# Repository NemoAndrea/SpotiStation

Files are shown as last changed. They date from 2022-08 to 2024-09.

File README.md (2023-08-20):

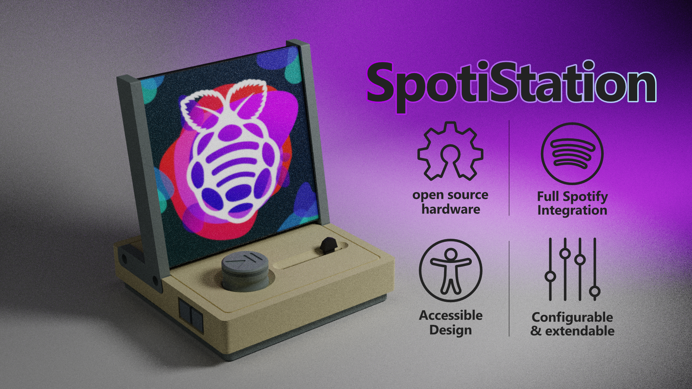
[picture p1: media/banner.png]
banner image


# SpotiStation - an accessible music player
A **Raspberry Pi** powered **Spotify** music player that aims to be **easy to use for people with cognitive or physical disabilities (e.g. Alzheimer's or MS)**, and allow them to enjoy music independently. 

To suit this purpose, the music player has an **extremely simple interface & operation**. A big play/pause button, a physical linear volume slider, and two side buttons that handle convenience functions, but can be omitted.

While accessibility is the primary aim of the design, this does not mean it cannot be used by a broader audience. If you like the idea of seeing the album art of your Spotify songs, and the physicality of hardware buttons, it would not look out of place in a living room. 

Features

* RGB led matrix that displays cover art and serves as basic visual interface
* Night mode that turns off the display and stops playback at user-set interval
* Lock mode, for caretakers to stop playback for a day
* Audio playback via Bluetooth simplifies wiring and mounting
* Only one plug (power supply)
* Configurable playlist selection, only use a subset of your Spotify playlist for playback
* Playback controllable via Spotify API (e.g. via phone or computer)
* Total parts cost €163 (**excluding printed parts**).
* 3D printed enclosure, making modification easy
* Open python code, low barrier to modification

> **Note** SpotiStation does **not** have any built-in speakers, it needs external bluetooth speakers.

> **Note** SpotiStation is a **standalone** Spotify player and does **not** require a computer or mobile device to run or handle any aspect of playback, although these devices integrate well with the device thanks to the Spotify multi-device API.

### 📖 Manual

A usage manual explaining features and going into details about how features are implemented can be found [on the project wiki](https://github.com/NemoAndrea/SpotiStation/wiki).

### 🔨 Assembly

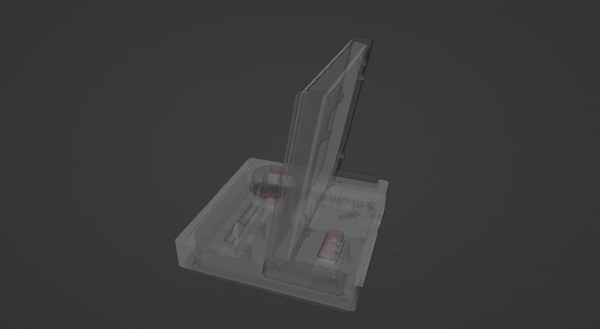
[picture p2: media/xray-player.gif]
xray view of spotistation


The assembly of the music player will require some dexterity, screwdrivers, and soldering setup and know-how. If you don't have a soldering setup, you could ask a friend or look for a [maker space](https://en.wikipedia.org/wiki/Hackerspace) that will have the right gear.

A [step-by-step walkthrough of assembly](docs/assembly.md) is available. 

> Feedback on what parts of the assembly are not explained well or are particularly complicated is greatly appreciated. Overly complicated steps could be fixed in future design revisions.

If you find yourself in a situation where accessing the SpotiStation is often difficult and moving the player is not an option, you could consider sourcing the parts for and printing a wireless remote 🎮 for the system. Total parts cost (excluding printed parts) is only around 10 euros, so it is cheap to add. Check out the separate instructions for [the simple wireless remote](docs/assembly-optional-remote.md).

### 💻 Software Setup

The software setup is streamlined as much as possible, but there are some unavoidable difficult steps due to the need to fetch API keys and such for Spotify. If you know how to SSH into your Raspberry Pi, you should be good to go.

The [full step-by-step walkthrough](docs/setup.md) should let you get your own player up and running in no time! 

### 🤔 Alternative solutions

There are other simple music player that focus on accessibility for people with physical or cognitive disabilities. I suggest you check them out and see if they may be better suited for your needs. They are not open source or easily modifiable, but require minimal setup. 

* [the bbrain player](https://bbrain.eu/bbrain-muziekspeler/) - super simple operation, radio and MP3, nice administrator features (hide buttons)
* [The lift Player by smpl](https://smpltec.com/liftplayer-buy-now-us) - super simple operation, plays MP3 files, some administrator features (lock volume)
* [the relish radio player](https://relish-life.com/us/music/radios/relish-radio) - primarily a radio, but can playback MP3 from USB stick
* [the simple music player by iGuerburn](https://www.iguerburn.com/products/dementia-music-player) - plays MP3 files

And because open projects are cool, I will list some other open source projects below

* [dqmusicbox by Ross Porter](https://dqmusicbox.com/) - simple operation, plays MP3 files

### 🙏 Acknowledgements

The programmatically generated text in the UI uses the [silkscreen font by Jason Kottke](https://kottke.org/plus/type/silkscreen/). It is converted to a PIL font for display purposes.

This project is building on similar projects that use the RGB matrix to show album Art. A non-exhaustive list:

* The [spotipi project](https://github.com/ryanwa18/spotipi)  by Ryan Ward
* The [thirtytwopixels project](https://github.com/fspoettel/thirtytwopixels) by Felix Spöttel 

This project was significantly improved by insights gained during the [Delft Open Hardware Academy](https://www.openhardware.academy/01_Welcome.html).

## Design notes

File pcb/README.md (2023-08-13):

## SpotiStation shim PCB

This a simple PCB that minimises the spaghetti inside the SpotiStation enclosure. It should be fairly cheap to have it manufactured (less than 6 euros at [Aisler](https://aisler.net/)) with the most basic options.



### Edge.cuts

Board outline is specified in `edge-cuts.dxf` which is generated from the FreeCAD file `edge-cuts.FCStd` file using the 'new' dxf export.

To import it (or modified versions) to kicad, do the following:

1. Open PCB editor
2. File > Import > Graphics
3. Select the `edge-cuts.dxf` file 
4. Placement: at X=`150.82` Y=`106.32`. Make sure to import to the edge.cuts layer and keep the scale to 1. Line width can be chosen at random; 0.1mm is fine.

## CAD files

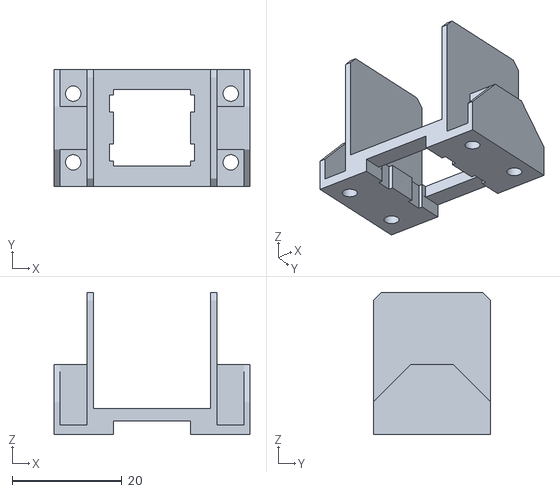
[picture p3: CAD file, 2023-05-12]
3D-printing/stl/MainButton-mount.stl
35.8 x 21.4 x 26.0

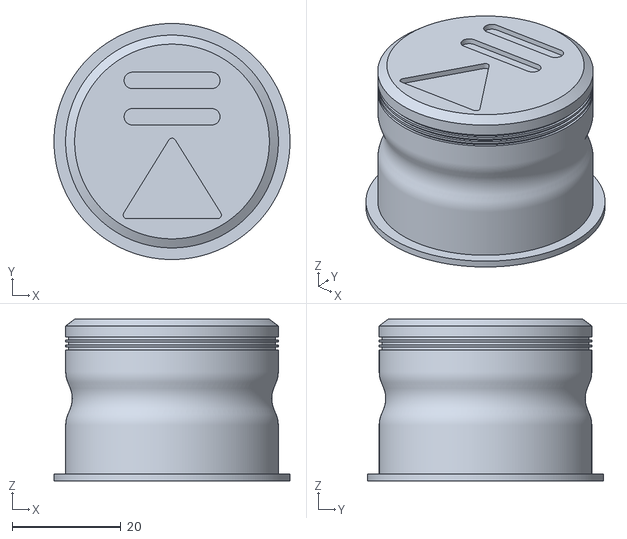
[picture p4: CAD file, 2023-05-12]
3D-printing/stl/MainButton.stl
43.3 x 43.3 x 29.7

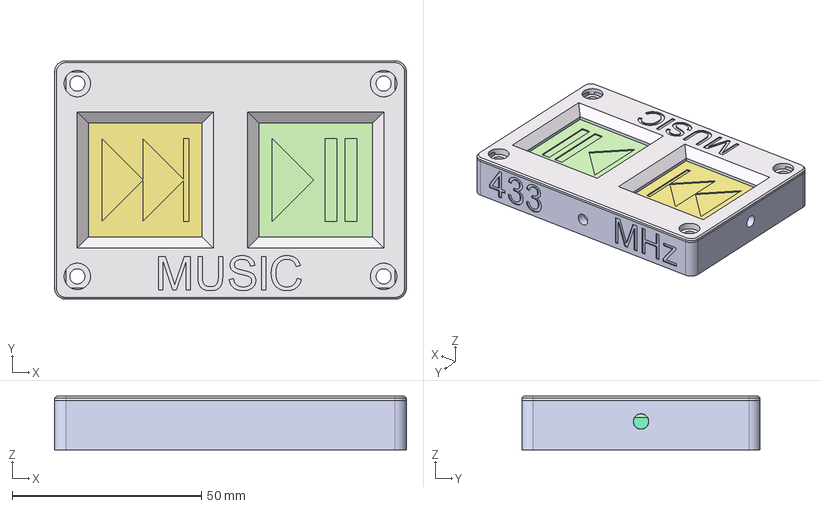
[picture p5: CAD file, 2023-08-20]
3D-printing/source/remote.FCStd
93.0 x 63.0 x 14.2 mm
remote-pcb
bulk
actuator-left
actuator-right
front-plate

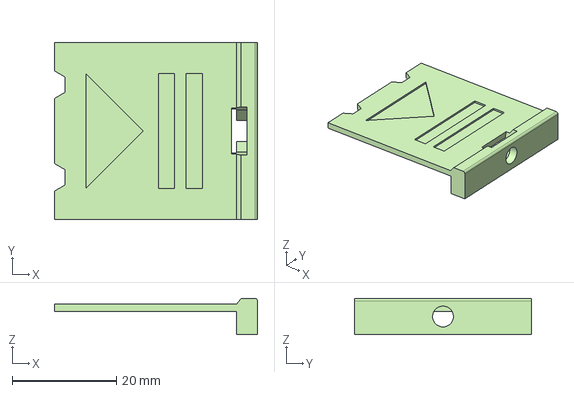
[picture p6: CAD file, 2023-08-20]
3D-printing/step/433_remote_button_RIGHT.step
39.0 x 34.0 x 7.00 mm

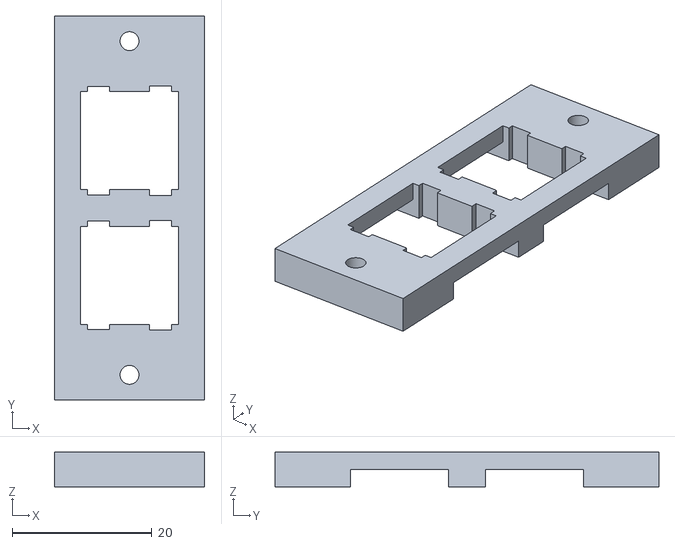
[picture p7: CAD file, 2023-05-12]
3D-printing/stl/Baseplate-button-bracket.stl
21.5 x 55.0 x 5.00

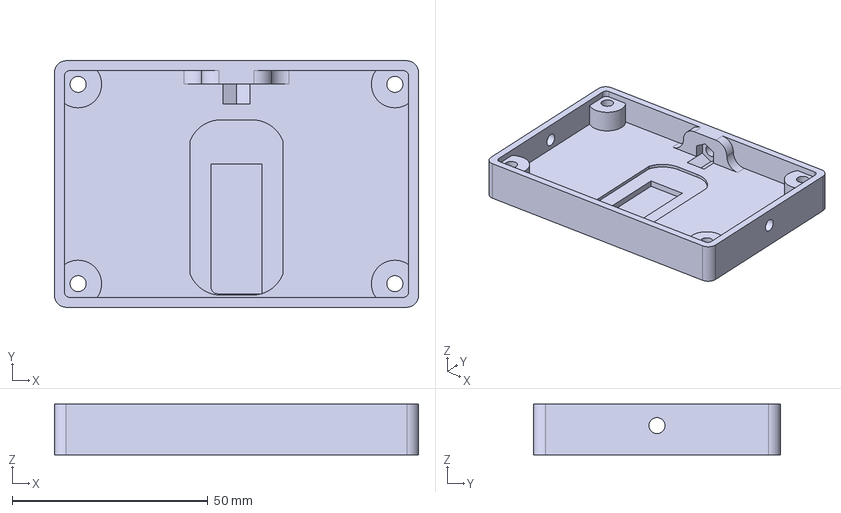
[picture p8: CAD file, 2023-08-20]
3D-printing/step/433_remote_base.step
93.0 x 63.0 x 13.0 mm

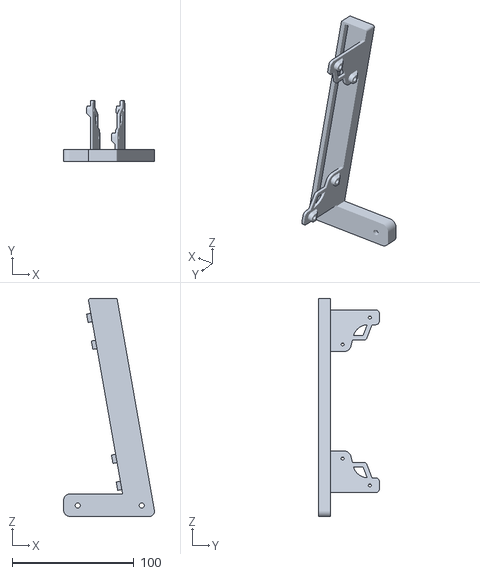
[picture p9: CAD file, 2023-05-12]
3D-printing/stl/Display-Arm-Left.stl
74.6 x 49.9 x 178.8

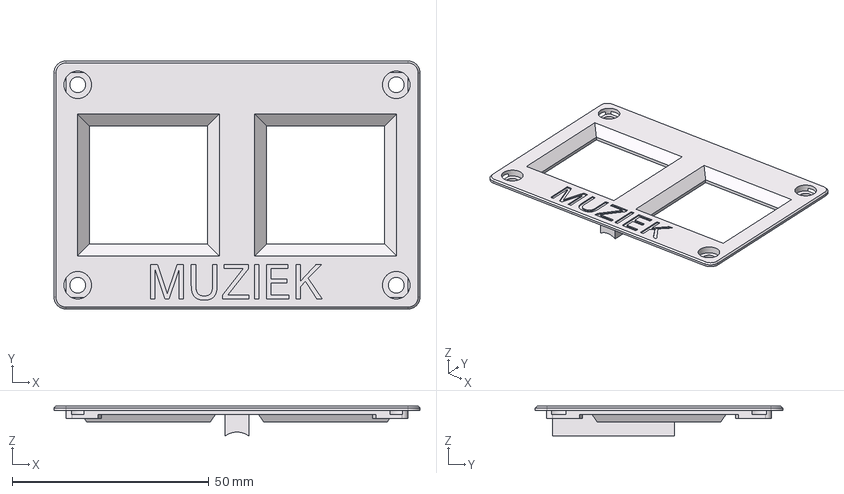
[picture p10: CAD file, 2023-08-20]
3D-printing/step/433_remote_lid.step
93.0 x 63.0 x 7.61 mm

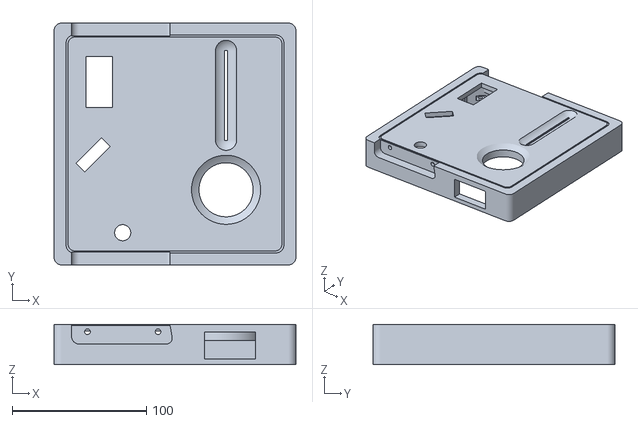
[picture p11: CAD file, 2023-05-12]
3D-printing/stl/Case.stl
180.0 x 180.0 x 30.0

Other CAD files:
pcb/edge-cuts.FCStd
3D-printing/step/433_remote_button_LEFT.step
3D-printing/stl/Display-Arm-Right.stl
pcb/edge-cuts.dxf

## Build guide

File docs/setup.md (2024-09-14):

# Software Setup 

> [!CAUTION]
> The instructions in the section below can be a bit technical and should be streamlined. If you are planning on following them and get stuck, feel free to send an email and I will try to help out.

We are assuming the code is run from a raspberry pi running `Raspberry Pi OS Lite 32-Bit` and that the raspberry pi has some way to connect to Wi-Fi. Bluetooth connectivity is required if speakers are to be driven wirelessly (as opposed to via 3.5mm jack of the Pi).

> [!IMPORTANT]
> We are assuming you will configure your installation of Raspberry Pi OS with username `musicpi` and device name `SpotiStation`. 

Raspbian OS Lite comes with A Python 3 installation, and a GPIO library, so that will be pre-installed. But we will still need to get `pip` installed. 

```
sudo apt-get install python3-pip -y
```

To drive the **Adafruit NeoSlider** we will need to get the appropriate package

```
pip3 install adafruit-circuitpython-seesaw
```

In addition, we will need to activate the `I2C` (hardware) interface on the Pi (disabled by default). We can do this in the configuration of the raspberry pi. 

```
sudo raspi-config
```

In the configuration menu, go to `Interface Options`, enable `I2C` and close out of the menu. 

For reasons that are not entirely clear to me, the NeoSlider does not work well with the default i2c bus frequency. It will randomly lock up the bus, or read values beyond it's normal valid range (0,1023). To fix this, we need to [change the i2c bus frequency to 400kHz](https://gist.github.com/ribasco/c22ab6b791e681800df47dd0a46c7c3a) on the Pi. 

1. Open system config `sudo nano /boot/config.txt`. Be careful not to mess anything up there.
2. Find the line `dtparam=i2c_arm=on` 
3. Add `i2c_arm_baudrate=400000` to the **same** line (comma separated), so it now reads `dtparam=i2c_arm=on,i2c_arm_baudrate=400000`
4. Save and exit `nano` (ctrl s, ctrl x)
5. Reboot (maybe even power cycle)

We will also need to be able to control the system volume, for which we will need another python package

```
pip3 install pyalsaaudio
```

### 💾 Download the SpotiStation code

We will need to get the SpotiStation code onto the raspberry Pi. You can either

1. Clone this repository directly (this will get you the latest version of the code)
2. Download the latest release (generally older but more stable in principle)

Whichever option you chose, we want the contents to be stored in a folder called `SpotiStation` located **in the home directory**. Make one and enter it by

 ```
cd 
mkdir SpotiStation
 ```

And then for option (1) we use

```
git clone https://github.com/NemoAndrea/SpotiStation.git SpotiStation
```

And for option (2) 

```
curl -L https://api.github.com/repos/NemoAndrea/SpotiStation/tarball/<version> -o spotistation.tgz
tar -xvf spotistation.tgz --strip-components=1 -C SpotiStation
```

Where you replace `<version>` with whichever release is the latest, e.g. `v0.1.0`

### 🌈 RGB panel setup

We follow [Adafruit's guide](https://learn.adafruit.com/adafruit-rgb-matrix-bonnet-for-raspberry-pi/driving-matrices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) and install the drivers by Henner Zeller h.zeller@acm.org. Download and run the installer script by:

```
curl https://raw.githubusercontent.com/adafruit/Raspberry-Pi-Installer-Scripts/main/rgb-matrix.sh >rgb-matrix.sh
sudo bash rgb-matrix.sh
```
And follow the instructions in the installer script. We are using the matrix bonnet, not the hat with RTC. We also want the `quality` option.

* Solder jumper between 4 and 18, picture quality is not good enough without. Analog audio (3.5mm jack or HDMI) will be disabled, but Bluetooth audio is fine.
* Enable the CPU core reservation (pi 3, zero 2, and 4) in `/boot/cmdline.txt`, by adding `isolcpus=3` to the file (space separated from other items in that file). Example contents: ```console=serial0,115200 console=tty1 root=PARTUUID=060e4657-02 rootfstype=ext4 fsck.repair=yes rootwait isolcpus=3``` 

### 🎵 Setup - Spotify (background)

To stream Spotify, we will use [spotifyd](https://github.com/Spotifyd). We need to install the latest release (for ARMv6), as per the instructions laid out on [their raspberry pi guide page](https://spotifyd.github.io/spotifyd/installation/Raspberry-Pi.html). For completeness I will cover the contents of their page here. If in doubt, follow the instructions on `spotifyd`'s page.  Make sure you get the latest release. At the time of writing, the latest version is `0.3.3`, so we install that with:

```
wget https://github.com/Spotifyd/spotifyd/releases/download/v0.3.3/spotifyd-linux-armv6-slim.tar.gz
```

> This setup assumes you are downloading this into your home directory on the raspberry pi. (type `cd` to go there if you are not sure)

The command above will give you a `tar.gz` archive, which you can unpack with

```
tar -xf <name of downloaded file>.tar.gz
```

Now we need to create a config file where we set up`spotifyd` to our liking.

```
mkdir ~/.config/spotifyd/
```

> It may be the case that you do not have a `.config` folder on your Pi. If so, just create an empty one by `mkdir ~/.config`

and again we must create and edit this file in `nano` (use `nano ~/.config/spotifyd/spotifyd.conf`) and paste the following information into it:

```toml
[global]
#username_cmd = "jq -r .username /home/musicpi/.cache/spotifyd/credentials.json"
backend = "alsa"
#device = alsa_audio_device # Given by `aplay -L`
mixer = "PCM"
volume-controller = "alsa" # or alsa_linear, or softvol
#onevent = command_run_on_playback_event
device_name = "SpotiStation"
bitrate = 320
cache_path = "/home/musicpi/.cache/spotifyd"
volume-normalisation = true
normalisation-pregain = -10
```

(optional): `device` uncomment this line (remove `#`) and set a device if you want to select a specific output for audio (e.g. HDMI/Bluetooth)

> If you use Facebook login for Spotify, you will need to go to Spotify's website and look at your account settings. You should be able to find a numerical username. This is the username you will want to use for `spotifyd`. As for the password, you will probably have to request a 'device password' somewhere in the account settings in Spotify. This takes less than 3 minutes.

If you have created your config, it would be good to check if its all working before making the daemon start up automatically. Give it a whirl by typing `~/spotifyd --no-daemon`. **You should get some information about the information it is using and if it managed to make a connection. If you go to Spotify on your phone or pc, the device should now be listed in playback devices (as 'SpotiStation')!**

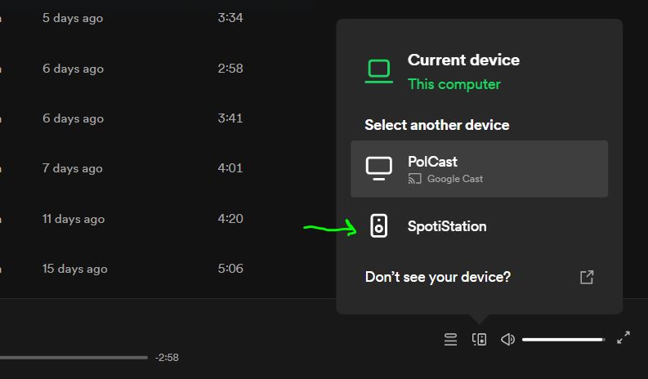
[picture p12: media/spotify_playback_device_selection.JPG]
spotify device playback menu showing spotistation listed


If you managed to connect to the device as a spotify playback device and tried to play some music over it, a new file should have been created in `/home/musicpi/.cache/spotifyd` called `credentials.json`. If that file exists, you can uncomment the line with `username_cmd`. Next time the service is run, it will be listed as one of your speakers (rather than one that your account has never seen before).  

If everything worked up to this point, it is time to set `spotifyd` to start when the raspberry pi is booted. That way we always have it running and ready to play! Let's make a service file for `systemctl` to run.

```bash
mkdir -p ~/.config/systemd/user/
nano ~/.config/systemd/user/spotifyd.service
```

This will open the text editor `nano`. You  need to copy the contents of [github.com/Spotifyd/spotifyd/blob/master/contrib/spotifyd.service](https://github.com/Spotifyd/spotifyd/blob/master/contrib/spotifyd.service) into it. As before, use the most up-to-date version that is found at that URL. For completeness, this is the version I used:

```toml
[Unit]
Description=A spotify playing daemon
Documentation=https://github.com/Spotifyd/spotifyd
Wants=sound.target
After=sound.target
Wants=network-online.target
After=network-online.target

[Service]
ExecStart=<path to where you unzipped spotifyd - e.g. /home/<username>/spotifyd> --no-daemon
Restart=always
RestartSec=12

[Install]
WantedBy=default.target
```

And then we can run `systemctl --user daemon-reload`. And then give the background process a test run with `systemctl --user start spotifyd.service`. Check in Spotify if the raspberry pi showed up in playback devices after running that command.

If it's working, all we need to do is ensure this runs on startup. This is simple with the two following commands:

```bash
sudo loginctl enable-linger <username>
systemctl --user enable spotifyd.service
```

Let's do one final check if its all set up right: shut down your raspberry pi (`sudo shutdown -h now`) and the raspberry pi should disappear from Spotify devices after a short while. Now start up the raspberry pi and see if it shows up in Spotify devices automatically!

### Setup - Spotify (API control)

While `spotifyd` actually handles the audio streaming, it does not control playback. Playback control and playlist selection etc is done via the Spotify API. Luckily, there is a python package for this [called spotipy](https://pypi.org/project/spotipy/). Let's install it

```
pip3 install spotipy
```

We need to get credentials for the api, which we can realise by making an 'app' in the [spotify developer bashboard](https://developer.spotify.com/dashboard/applications). Go to the dashboard, add  a new app, and from that new app get the `client id` and the `client secret` and `redirect url`.

> Redirect url is best set to something local; I suggest `http://localhost:8888/callback`.  You will need to set this in the Spotify dashboard in your app under the app-specific settings.

We will put these credentials in environment variables as one would not want to have this included in the repository. In the Raspberry Pi's terminal, fill out the following statements. 

```
export SPOTIPY_CLIENT_ID='your-spotify-client-id'
export SPOTIPY_CLIENT_SECRET='your-spotify-client-secret'
export SPOTIPY_REDIRECT_URI='your-app-redirect-url'
```

then navigate into the SpotiStation repository and run `python /src/cache_spotipy_credentials.py` and follow the instructions. If all is well, you will be shown a link. Paste that link in a browser where you are signed into Spotify. You will be asked to agree to some terms. Read the terms, agree and then you will be shown a blank/error page. **This is not a mistake!** The URL of the page will actually contain a code that you need to paste back into your terminal! Copy **the entire** url and paste it into the terminal as asked. Check that after this procedure a `.cache` file was generated in the current directory.

> **🚧 This section is in need of revision - the cache file is currently not used.

If that went well a `.creds` file should have been generated. Move it into the root folder of the repository (so out of `src`). 

Now you can use 

``` python
import spotipy
from spotipy.oauth2 import SpotifyOAuth

sp = spotipy.Spotify(auth_manager=SpotifyOAuth())
```

and use it as you would expect

## Setup - Bluetooth speaker

Apparently you cannot use Bluetooth and Wi-Fi at the same time on a RPi with the built-in system so a dongle is needed. Let's use  a dongle for Bluetooth and disable the internal one in `/boot/config.txt,`.

```
dtoverlay=pi3-disable-bt-overlay
```

Apparently, `raspbian OS lite` does not come with all the bits and pieces needed to connect to Bluetooth speakers. Luckily, [others have treaded before](https://www.okdo.com/project/set-up-a-bluetooth-speaker-with-a-raspberry-pi/).  For whatever reason, `pulseaudio` is  required for this.  Let's install it by

```
sudo apt install pulseaudio-module-bluetooth
```

We also need to change some permissions of our main user account (find it by typing `who` in terminal). You will have chosen this name when you generated a Raspbian OS installation image.

```
sudo usermod -a -G bluetooth <useraccount>
```

And reboot the Raspberry Pi (`sudo reboot`)

Now we start connecting to the speaker. First we must use the `bluetoothctl` command to be brought into a separate CLI. Turn on your Bluetooth device, and **make sure it is in pairing mode (if connecting for the first time)**. In this new CLI, type

```
scan on
```

wait for your speaker to show up (your speaker should be listed by name - give it a minute to scan for devices). Once you see your speaker name, we can stop the scanning  by `scan off`. Now we must make a note of the *Bluetooth MAC address* (e.g. 00:11:22:33:FF:EE). Then, with the Bluetooth speaker in pairing mode, enter

```
pair <MAC adress>
trust <MAC adress>
```

Now we are paired (**but not connected**) with the device - this is the one-time setup part.  To actually connect, type

```
connect <MAC adress
```

## Setup - run slider volume control as service

We run the volume control via the slider as a separate scrip to ensure we can always adjust volume even if the main program crashes. So, let's set that up.

```
nano ~/.config/systemd/user/rpi-spotiplayer-volume.service
```

And make the file contents:

```
[Unit]
Description=Volume control handler for SpotiStation

[Service]
Type=simple
WorkingDirectory=/home/musicpi/SpotiStation
ExecStart=/usr/bin/python /home/musicpi/SpotiStation/src/regulate_volume.py
Restart=always
RestartSec=5

[Install]
WantedBy=default.target
```

Next, make the service runnable:

```
sudo chmod 644 ~/.config/systemd/user/rpi-spotiplayer-volume.service
```

And finally make sure it runs after system boot:

```
systemctl --user enable rpi-spotiplayer-volume.service
```

## Setup - run music player as service

We need to ensure the music player runs as a service upon startup. We use the same approach as before, but specify that we want to run this as root, but still as a user.

> I must admit here that I am not entirely too sure how this whole root thing works, as a normal systemctl process (in /lib/) would make more sense, but that has no access to the  python environment so I am just going with what is below - which seems to work fine.

```
nano ~/.config/systemd/user/rpi-spotiplayer.service
```

We make the contents of the file the following:

```
[Unit]
Description=A python spotify music player service
Requisite=spotifyd.service
After=spotifyd.service

[Service]
Type=simple
WorkingDirectory=/home/musicpi/SpotiStation
ExecStart=/usr/bin/sudo -E /usr/bin/python /home/musicpi/SpotiStation/src/start_player.py
Restart=always
RestartSec=60

[Install]
WantedBy=default.target
```

> We set it such that it will restart automatically when the python script exits (which will only happen in case of an error)

We make it active via: 

```
 sudo chmod 644 ~/.config/systemd/user/rpi-spotiplayer.service
```

And then we update our `systemctl` process by running `sudo systemctl --user daemon-reload`. As before, it is good to see if it works before making it run on start-up by running `systemctl --user start rpi-spotiplayer.service`. That should start the player as normal after few seconds. 

If that all seems to work well, stop the process and set it up for running at boot:

```
systemctl --user enable rpi-spotiplayer.service
```

### .bashrc setup

Nice to have, but not needed

```bash
alias startplayer='systemctl --user start rpi-spotiplayer.service'
alias stopplayer='systemctl --user stop rpi-spotiplayer.service'
alias restartplayer='systemctl --user restart rpi-spotiplayer.service'
# in case you want to manually start the player and observe the log in terminal via SSH
# make sure the service is stopped and that you are in the repository directory
alias startplayer_manual='sudo -E python ~/SpotiStation/src/start_player.py'
```

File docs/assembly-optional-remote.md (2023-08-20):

## 🎮 433MHz remote for SpotiStation

It is possible to add a simple 433 MHz remote to your SpotiStation build. This can be useful if the main player is not always accessible (e.g. when the user spends a lot of time in bed). 

😀 Keep in mind that since a remote will probably be designed around the user, you may want to deviate from the design below. Feel free to do so, and use the example below for the functional part, and design a shell of your choice around it!

### 📜 List of components

| Vendor | Item | Amount | vendor ID | cost, total (euro) |
| --- | --- | --- | --- | --- |
| Soldered.com | 433MHz 4-channel remote controller | 1 | 108325 | 4 |
| Tinytronics  | RXC6 Superheterodyne receiver with recognition function | 1 | 711 | 5 |
| Tinytronics  | 433 MHz antenna | 1 | 242 | 0.5 |
| | 10mm M4 bolts and nuts | 7 | | 0.5 |

Total: **10 euro** (excluding printed parts)

_Note that the vendors are not critical; many stores stock essentially the same product. Have a look at the images below or look up the listed vendors above to find an equivalent at your suppliers_

### 🧰 Tools

To assemble your own remote, you will need

* Hex screwdriver or similar to secure 10mm M4 bolts
* Soldering iron to attach antenna to receiver (1 joint)
* Tools to open up SpotiStation to install receiver

### 🖨️ 3D printing

There are [4 components](../3D-printing/step) (starting with `433_remote...`) to be printed for the remote; they are not large and they all fit on the build plate. The recommended print orientation is given in the image below.

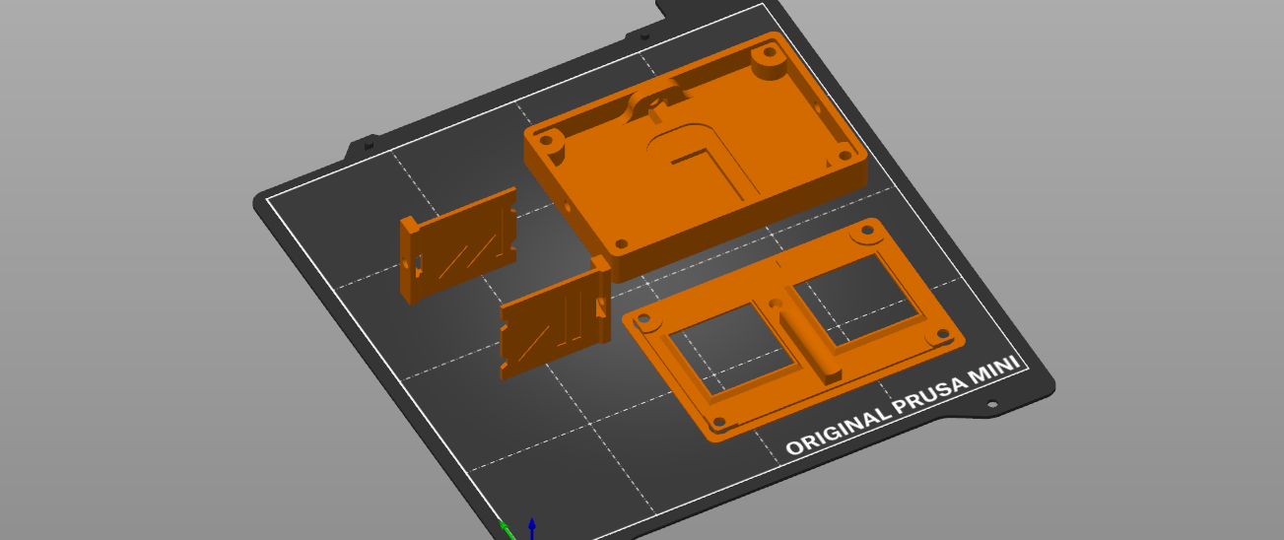
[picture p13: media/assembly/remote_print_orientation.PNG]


I suggest you also print the buttons in a different colour, to make it easy for the user to recognise and remember what the function of each button is.

> [!WARNING]
>
> The buttons are very thin and may fall over during printing. A brim may be useful for these parts to ensure they print reliably.

### 👷 Assembly & setup

Assembly and setup is pretty quick, and consists of the following parts:

1. Assembly of the printed remote parts
2. Wiring up the receiver & pairing it with the remote.

#### Assembly of printed parts

Start by stripping the basic 4-button remote out of its casing. 

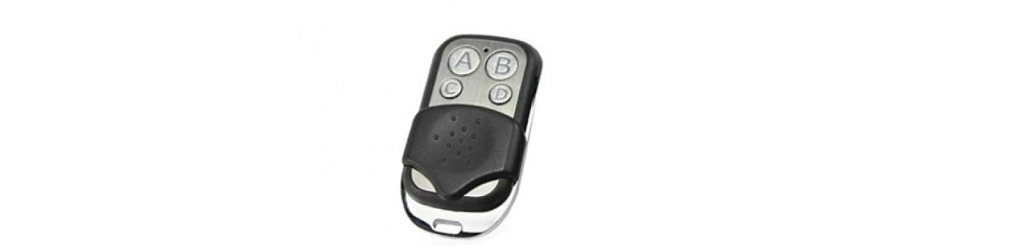
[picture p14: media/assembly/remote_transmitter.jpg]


It should now fit in the printed base part (note the orientation):

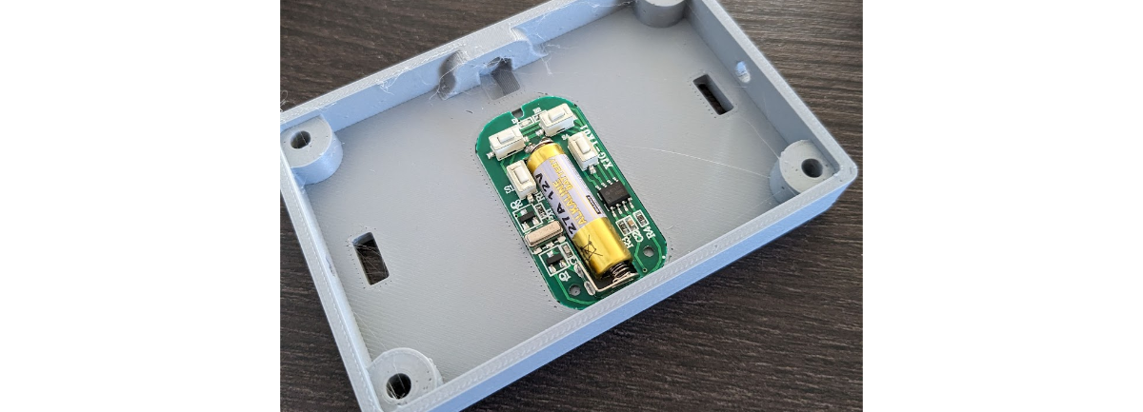
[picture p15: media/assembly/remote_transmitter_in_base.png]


Now install the button covers (that function as levers and significantly increase the interaction area). Be careful not to overtighten the bolts as the parts are pretty thin and will crack easily. 

Finally, simply install the cover and secure it with 4 M4 bolts. Now it should look something like this:

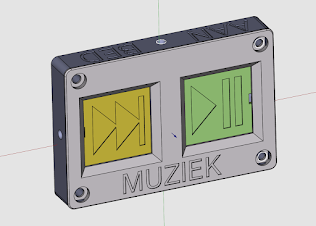
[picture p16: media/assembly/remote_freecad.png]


Depending on your use case, you can design a hook, anchor or other attachment mechanism that attaches to the M4 bolt point on the topside of the remote.

#### Receiver installation and pairing

For the receiver to work you will need to solder a 433 MHz antenna onto the pin socket labelled `ANT`. Some receivers may come with an antenna included in the box, but any 433 MHz rated one will work.

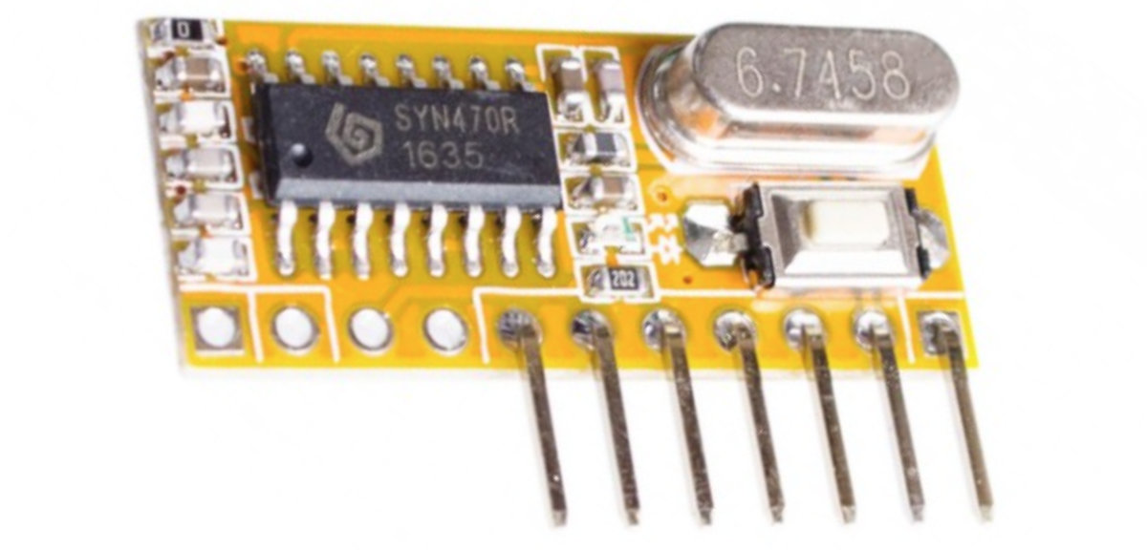
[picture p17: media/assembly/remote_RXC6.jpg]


Then you simply connect 3.3V to the power pin and ground (see the SpotiStation PCB for the easiest connection) and the remaining pins are determined after pairing.

Consult the manual for the specific receiver you have for pairing. The RXC6 has a simple procedure where you simply press the (only) button on the receiver untl you see the led light up, let go and then press a button on the remote to pair it. Next time that button is pressed, the button data (4-bit signal) will be output on the pins. Since most remotes have 4 buttons or less, manufacturers simply have those four buttons output `0001` `0010` `0100` and `1000`.  

For SpotiStation, pair the 4 buttons on your remote. (you can verify their output pattern via multimeter if you suspect it is not  simply``0010` etc). Then it is a matter of trial and error (if you dont have a multimeter) to figure out which button corresponds to what pin on the receiver going high. You can simply do a random wiring to the raspberry pi pins (see the PCB) and switch them around until it is correct. The [test_hardware.py](../src/test_hardware.py) script will be useful for this.

You can put the receiver somewhere inside the spotistation electronics compartment. Avoid putting it near other noisy devices such as USB cables or the display data cable.  Front of the unit works well and seems to receive remote signals from anywhere in  a small appartment.

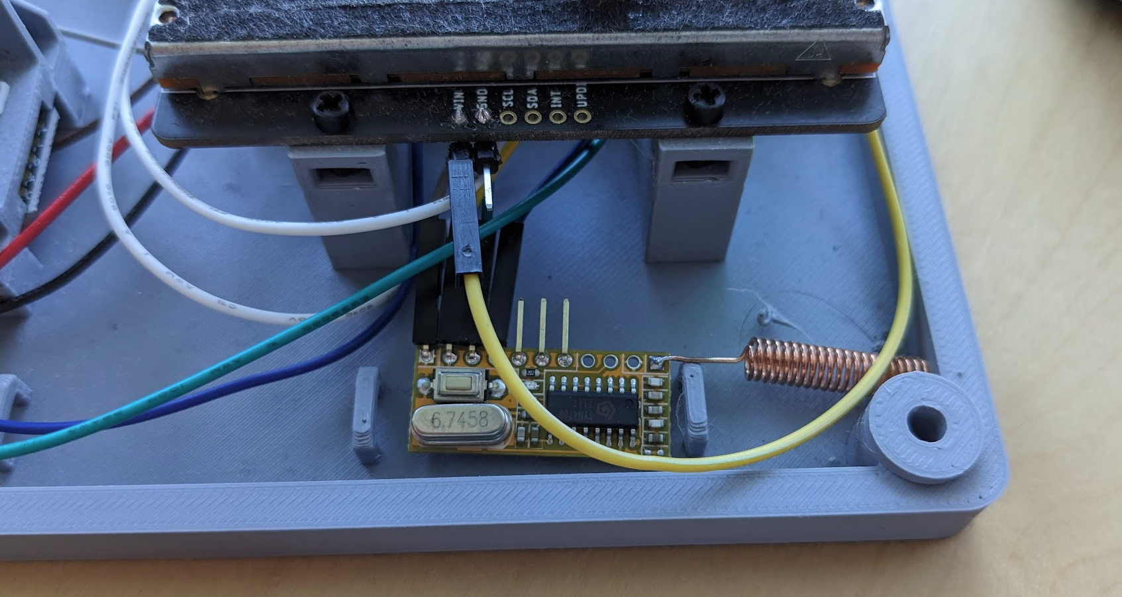
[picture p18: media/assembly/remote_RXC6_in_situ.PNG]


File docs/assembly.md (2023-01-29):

# 👷 Hardware assembly

### 📜 List of components

To build the SpotiStation, you will need to purchase the following items (or find alternatives).

| Vendor | Item | Amount | vendor ID | cost, total (eur) |
| --- | --- | --- | --- | --- |
| Digi-key | Raspberry Pi Zero 2 | 1 | 2648-SC0510-ND | 15 |
| Adafruit | 64x64 RGB LED Matrix - 2.5mm Pitch | 1 | 3649 | 53 |
| Adafruit | RGB Matrix Bonnet | 1 | 3211 | 15 |
| Adafruit | Black LED Diffusion Acrylic Panel 12" x 12" | 1 | 4594 | 9.6 |
| Adafruit | NeoKey Socket Breakout for Mechanical Key Switches with NeoPixel | 5 | 4978 | 8.4 |
| Adafruit | Adafruit NeoSlider I2C QT Slide Potentiometer | 1 | 5295 | 9.6 |
| Digi-key | 5V 3A power supply | 1 |	102-SWH15-5B-EB-P5-ND | 17.55 |
| Adafruit | Relegendable Plastic Keycaps for MX Compatible Switches 10 pack | 1 | 5039 | 4.76 |
| Adafruit | Any MX-style keyswitch, ideally with heavy spring | 5 | 5124 | 5 |
| Adafruit | Black Nylon Machine Screw and Stand-off Set – M2.5 Thread | 1 | 3299 | 17 |
| Adafruit | STEMMA QT / Qwiic JST SH 4-pin Cable with Premium Female Sockets - 150mm Long | 1 | 4397 | 1 |
| Adafruit | 2.54mm 0.1" Pitch 12-pin Jumper Cable - 20cm long | 1 | 4942 | 2 |
| Adafruit | Break-away 0.1" 36-pin strip right-angle male header (10 pack) | 1 | 1540 | 5 |

Total: **163 Euro**

*Full-size Raspberry Pi's will also work as long as they are version 3 or newer. For version 3 you may need a USB Bluetooth adapter.

**you can get any variety (clicky, tactile or linear), but in my opinion a linear is most appropriate, and especially for the main play/pause button it would be good to have a switch that has a heavy spring (force).

***If you already have a set at home, then of course there is no need to get a full box. You will need 12 `M2.5` screws (8x `6mm`, 4x `10mm`) and matching nuts.

In addition to the items above you will need:

1. 8x `M4` `16mm` bolts and nuts.
2. 8x `M3` `12mm` bolts.
3. The 3D printed parts. Printable `stl` files can be found in [the 3D printing directory](../3D-printing/stl), and sent to a commercial 3D printing company if you do not have a printer yourself. See the assembly section below.
4. A set of Bluetooth enabled speakers. This is totally up to you, but I would **strongly** suggest you chose a (set of) speakers that are **powered from mains** and not from a battery. An example would be the [Logitech Z207](https://www.logitech.com/de-de/products/speakers/z207-stereo-speakers-bluetooth.980-001295.html), which goes for about 45 euros.

### 🧰 Tools

To assemble your own SpotiStation, you will need

* Small screwdriver to tighten down `M2.5`  screws
* Medium/large screwdriver to tighten down `M4` and `M3` screws
* Soldering iron and solder, to solder some headers onto components
* Tools to cut acrylic panel (e.g. lasercutter or blade)

### 🖨️ 3D printing

There are 4 large parts that need to be printed, and 3 smaller ones. I suggest you pick two different colours to print with for visual interest, but can pick whatever colour you like of course. ⚠️ **Note that there are two versions of the baseplate part: one for the Raspberry Pi zero format, and one for the normal full size Raspberry Pi.** If you are interested in dimensions, you can have a look at [the schematics for the designs](../media/schematics) or the source files.

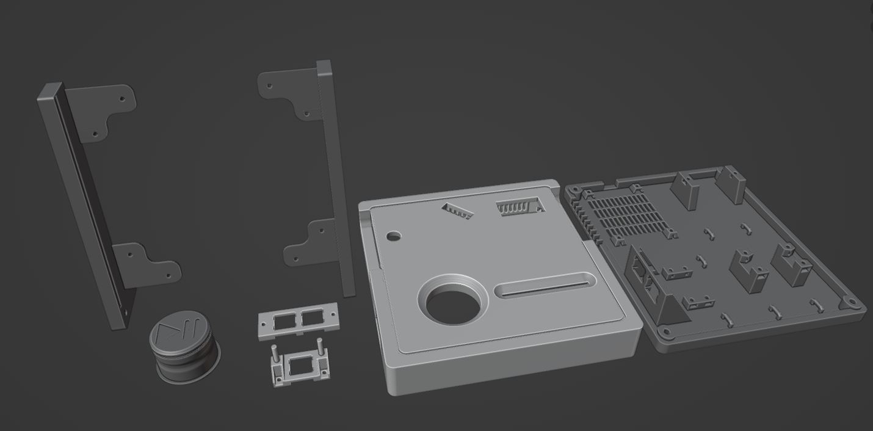
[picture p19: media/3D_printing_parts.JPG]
3d printable parts laid out


xray view of spotistation

All parts can be printed without supports on an FDM printer, and all parts fit* on the buildplate of small 3D printers such as a `Prusa Mini+`. I recommend the following orientations for the small prints. 

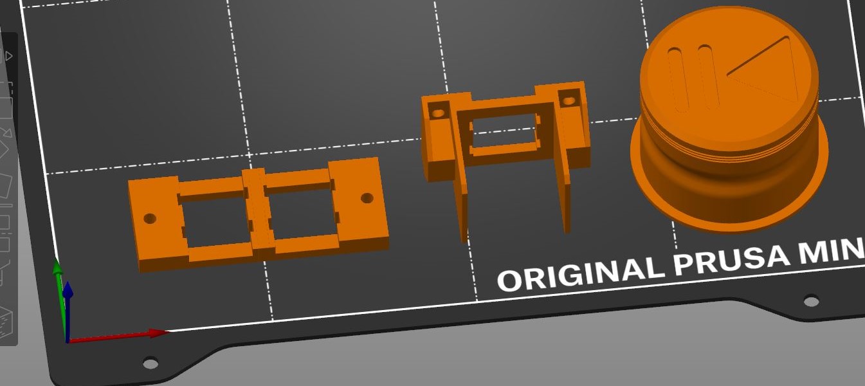
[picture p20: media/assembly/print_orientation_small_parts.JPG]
small print orientations on buildplate


The `case-top.stl` file *can* be printed without supports, but it is probably best to add some supports as depicted below.

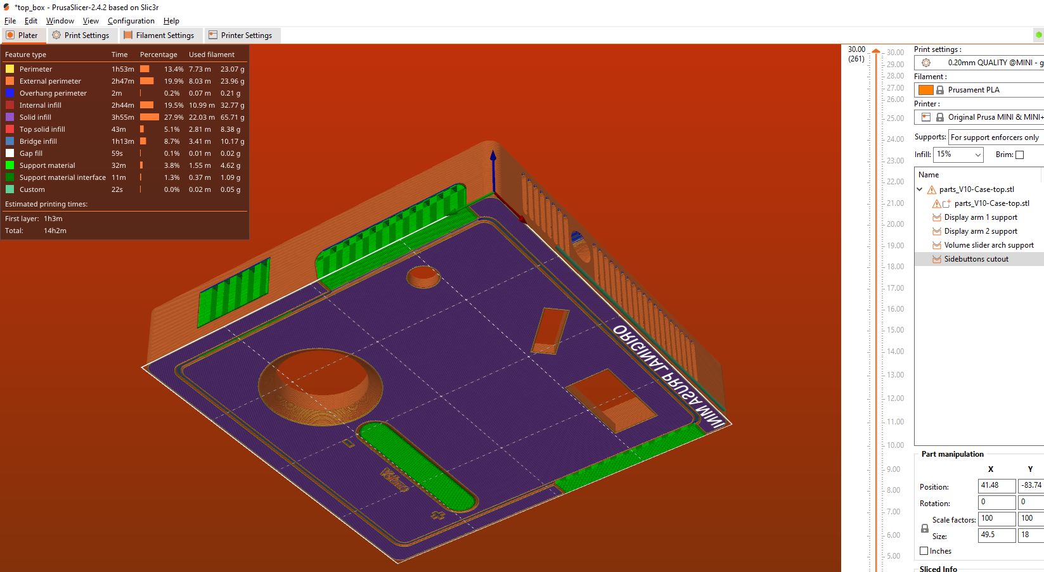
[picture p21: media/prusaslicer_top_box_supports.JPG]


*for the largest print it is important that you disable perimeters and purge lines on a `Prusa Mini+` as those end up outside the print volume.

### 👷 Assembly

With the parts printed, and supports removed, we can start assembly. There are two major parts to complete

1. The display assembly
2. The box assembly

Let's start with the simpler one, the display assembly.

#### Display assembly

Thread two M4 bolts (16mm) through the screw openings of the `display arms` and place in the correct position on the `top-box`

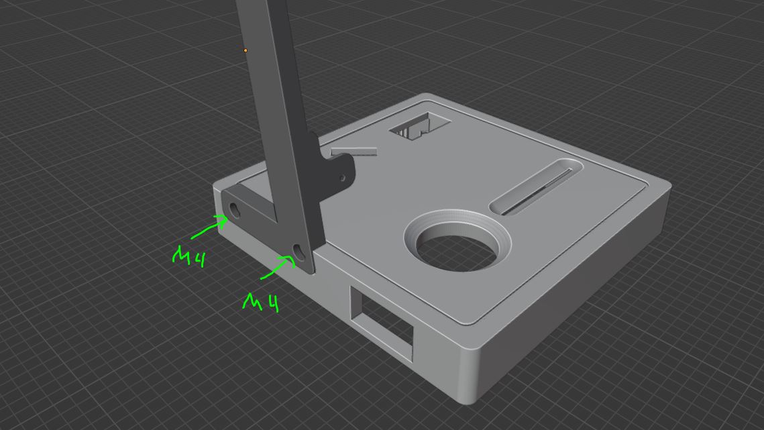
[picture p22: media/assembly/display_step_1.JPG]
display step 1


On the opposite side, (the 'inside' of the `top-box`), place two hex nuts and tighten the M4 bolts until tight. ⚠️ **Make sure that the hex nuts sit properly in the hexagonal cutout.**

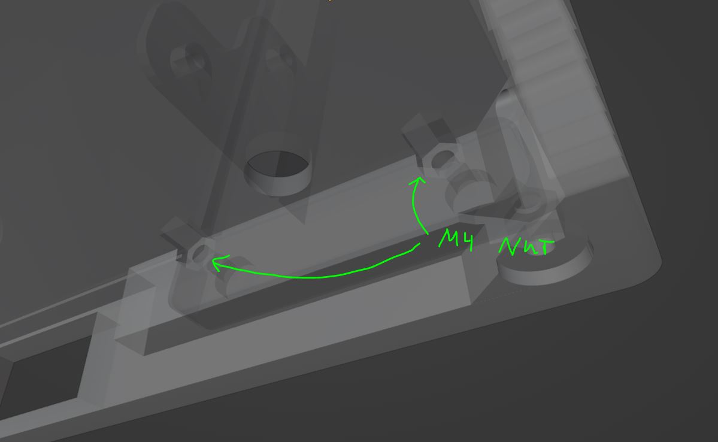
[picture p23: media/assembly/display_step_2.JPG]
display step 2


Cut the `display diffuser` panel (e.g. with a lasercutter or knife) to the correct size (**161 x 168mm**)  and place it in the corresponding groove in the `display-arm`. In the image below the panel is 168mm wide, and 161mm tall. ⚠️ **Make sure the matte side of the acrylic panel faces outward (towards the user).**

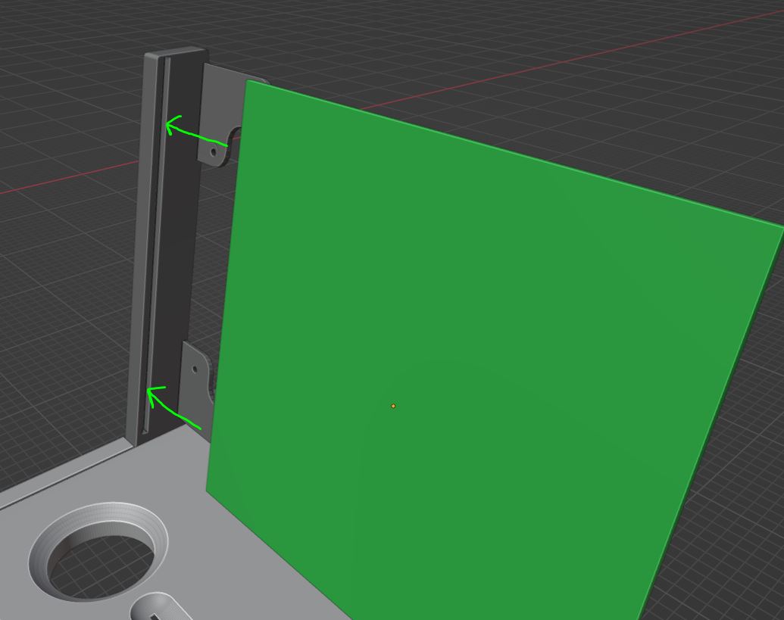
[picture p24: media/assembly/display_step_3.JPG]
display step 3 - diffuser


Now add the other `display-arm`. ⚠️ **Make sure that the `display diffuser` slots into the groove properly on that side too.**

Time to add the actual display panel. Slide it in from the top, in between the mounting points on the `display arms` and the `display diffuser`

⚠️ **The orientation of the display is important. Ensure that it sit such that the power connectors are at the bottom and top. (see image)**

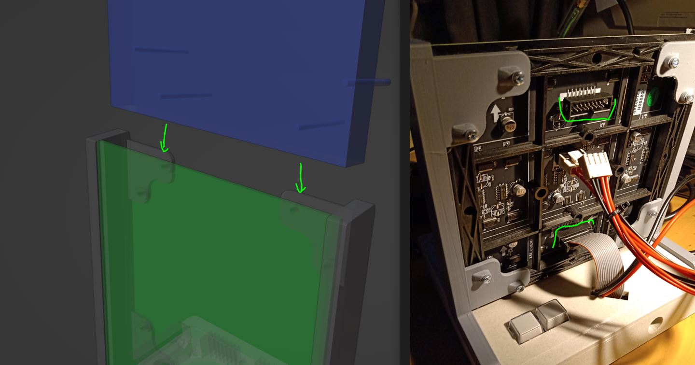
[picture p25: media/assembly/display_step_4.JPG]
display step 4 - rgb matrix


Secure the panel with 8 `M3` screws (12mm). 

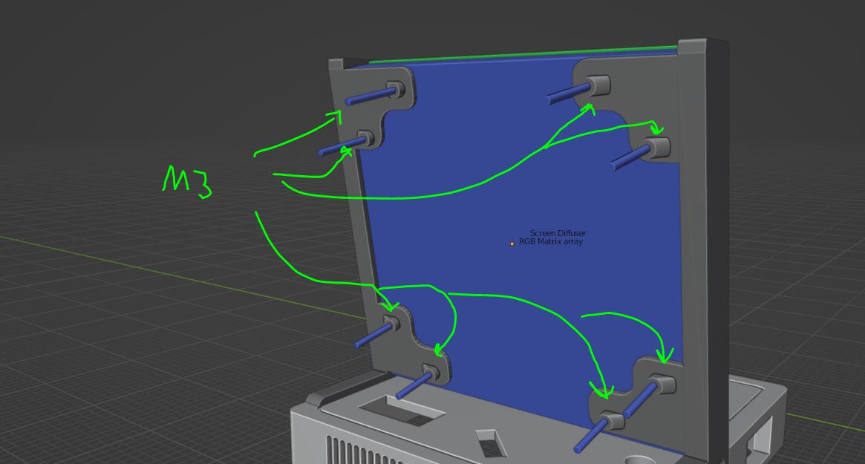
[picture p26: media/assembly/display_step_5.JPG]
display step 5 - m3


That's all for the display assembly, let's move on to the main electronics box!

#### Electronics box assembly

> A small note: all the hex nuts points on the prints have a large hole for insertion of the nut, and a smaller nut on the opposite side can be used to remove the nut in case it gets stuck, or some print debris is preventing complete insertion. During printing it is possible that some filament droops down and prevent the nut from sitting right. A bit of creativity with a screwdriver is generally sufficient to remove these stray strands of filament.

Start by connecting the `stemma QT` to the neopixel slider and mounting it on the `bottom-box`. ⚠️ **The neopixel slider has two stemma QT ports. Plug it in on the side with the Adafruit logo.** The slider is secured with 4 `M2.5` screws (10mm) and corresponding nuts. ⚠️ **The neopixel slider can be mounted in two ways. Mount it with the Adafruit logo away from the box edge as in the image below**

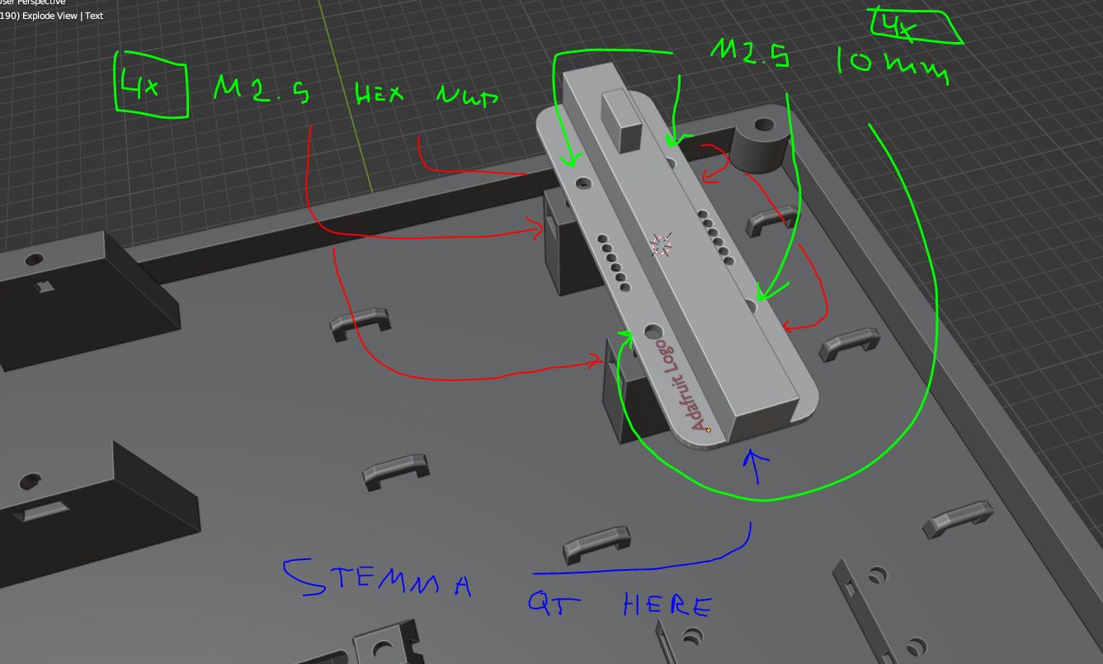
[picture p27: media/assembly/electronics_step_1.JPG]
electronics step 1 - slider


Now it's time to mount the Raspberry Pi. Mount it with the headers pointing up and the micro-SD card slot pointing towards the outside of the `top-box`. Secure the raspberry py with 4 `M2.5` screws (6mm) and corresponding hex nuts. The micro-SD slot remains accessible (if a bit hard to reach).

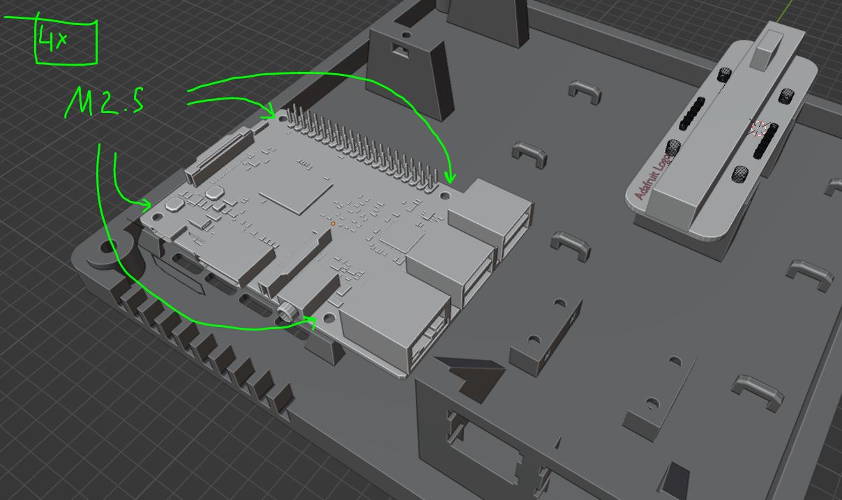
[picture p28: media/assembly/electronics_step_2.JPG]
electronics step 2 - raspberry pi


With the Raspberry Pi installed add the USB Bluetooth Dongle to one of the USB ports on the Raspberry Pi. Pick one of the two lower ones.

With the raspberry pi installed, we will have to get to the soldering of headers. Some of the soldering is going to be a bit ... unconventional, but I assure you that it is required to fit within the small space the enclosure affords.

We will need to solder:

1. Headers onto the `NeoKey Sockets` facing outward [3X]
2. Headers on the `NeoKey Sockets` facing inward [2X]
3. Headers onto the `RGB matrix bonnet` 
4. Adding headers to NeoSlider ground & solder ground wires together 

> **☠️ Warning: for your own health, always solder in a well ventilated area or have a system that extracts the soldering fumes.**

First, let's do the 3 outward sockets. It's going to be a huge help if you have something that can hold onto the parts while you solder (unless you have 4 arms).  Break off two pins of the right angled headers and solder them onto the NeoKey `S+` and `S-` holes (also labeled as C(athode) and A(node)).  **⚠️Ensure you are soldering on the side with the LED (otherwise the switch wont fit!).** Have the headers point outward.

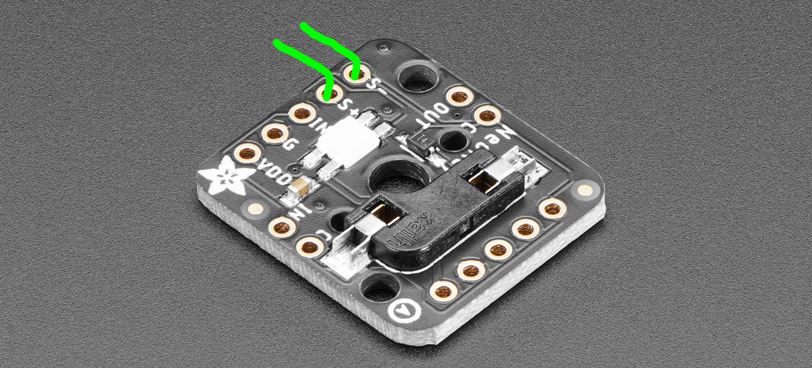
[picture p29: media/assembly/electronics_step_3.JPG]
electronics step 3 - outward soldering


For the 2 inwards sockets, we want to do the same: break off two right angled pins and solder them on the LED side of the PCB. Solder them on the NeoKey `S+` and `S-` holes. But this time we will solder the pins **inward** and have them span over the hotswap socket. See image below. 

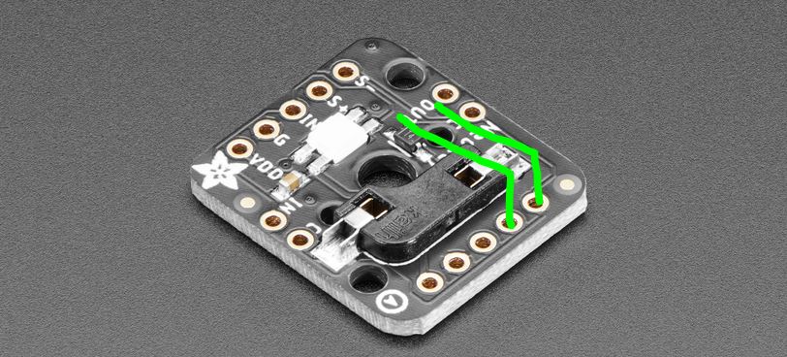
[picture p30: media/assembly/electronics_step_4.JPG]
electronics step 4 - inward soldering


Then we want to solder the RGB bonnet. Here we will need to solder the following items:

* 9 header pins
* a short bit of wire between pins 4 and 18 to improve the image quality, as is lined out in the [RGB bonnet guide](https://learn.adafruit.com/adafruit-rgb-matrix-bonnet-for-raspberry-pi/driving-matrices).
* A shorting piece of solder on backside pad (E to number 8)

 As there is limited room in the enclosure, we will again use the right-angled headers. I suggest you break of a set of 5pins, a set of 2 pins, and two single pins, and solder them as in the picture below. 

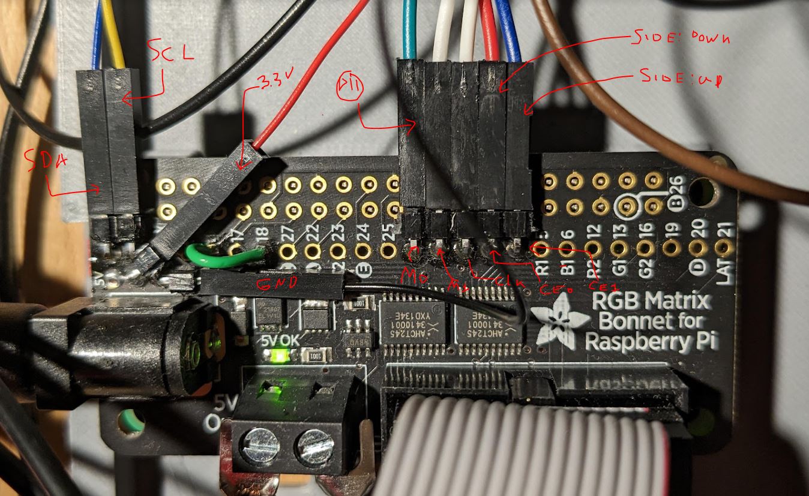
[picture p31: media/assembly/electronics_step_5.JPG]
electronics step 5 - RGB matrix bonnet


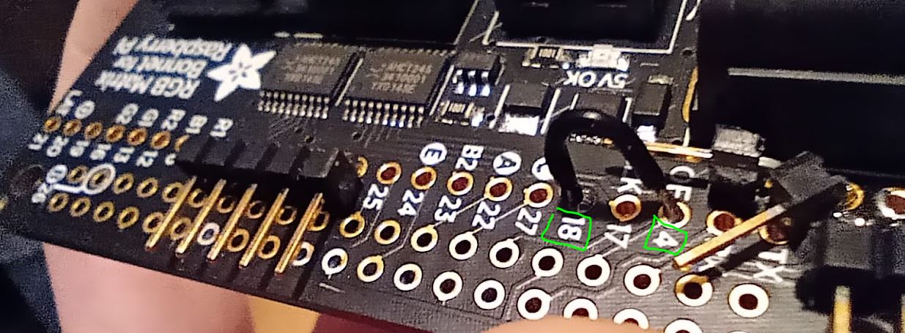
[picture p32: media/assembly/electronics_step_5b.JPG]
electronics step 5 - RGB matrix bonnet


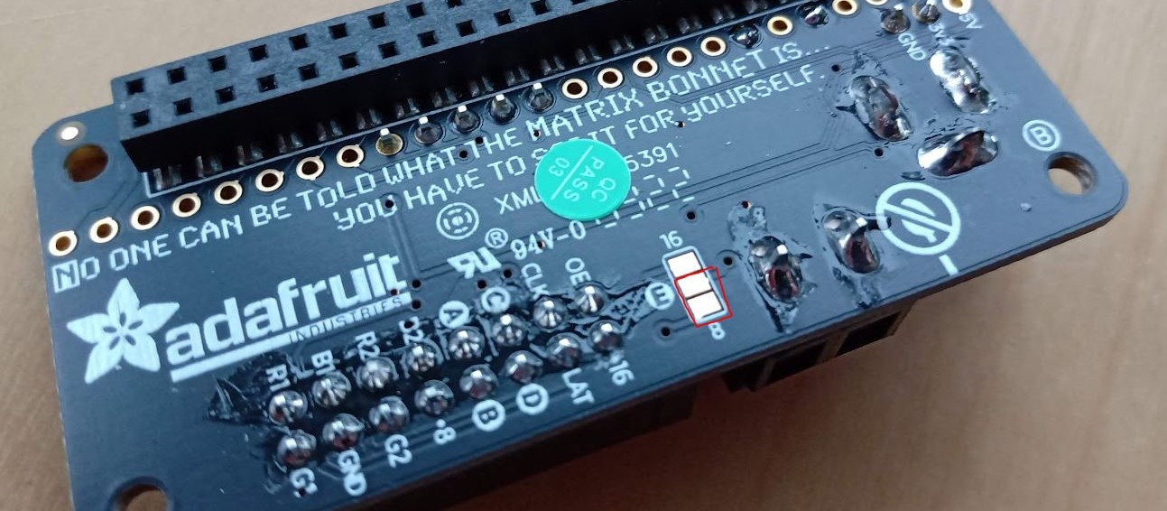
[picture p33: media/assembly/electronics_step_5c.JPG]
electronics step 5 - RGB matrix bonnet


Finally we solder some right-angled headers onto the NeoSliders so that we can make use of the ground pads on the slider. The RGB bonnet only has a single ground connection, which is used up by the StemmaQT cable, so we use the Slider `gnd` pads to ground our `NeoKeys`. We only need a header connected to ground. but a header of two pins is a lot easier to solder.

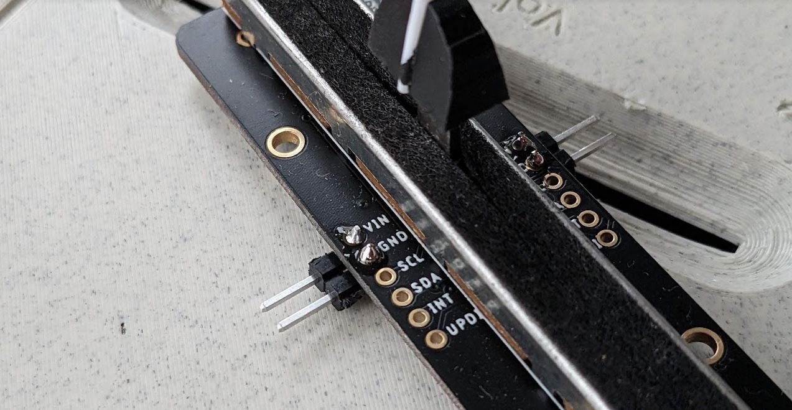
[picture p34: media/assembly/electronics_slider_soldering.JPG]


Now it is time to mount all the remaining components and wire it all up 🎉

To start with, add the  `RGB matrix bonnet` onto the raspberry pi. That should slide onto the Pi's headers with quite a lot of friction. 

Then, it is time to start connecting the switches. We will do the side buttons first. Click the MX-style switches into the ports on the side - the switches should snap right in and sit snugly.

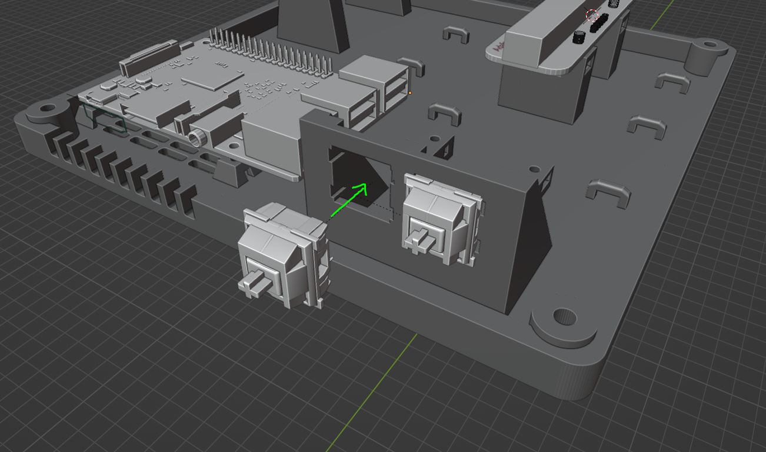
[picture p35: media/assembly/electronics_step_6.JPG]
electronics - mx switches side


On the backside (where the MX-switch pins are), add the *inward-facing* `NeoKeys`, with the headers pointing down as in the picture. *It ain't pretty but it will work.* I suggest you add some of the header wires onto the headers *before* you place them on the switches, but it is not a problem if you don't as the PCBs are only held in place by friction. 

> **Note**
>
> The 5 `S-` cables of the `NeoKeys` need to be wired to ground. The easiest way is to solder them to the `GND` pads on the `NeoSlider`. These are connected to the Raspberry Pi ground via the `Stemma QT` connections. 

It should look like the situation below:

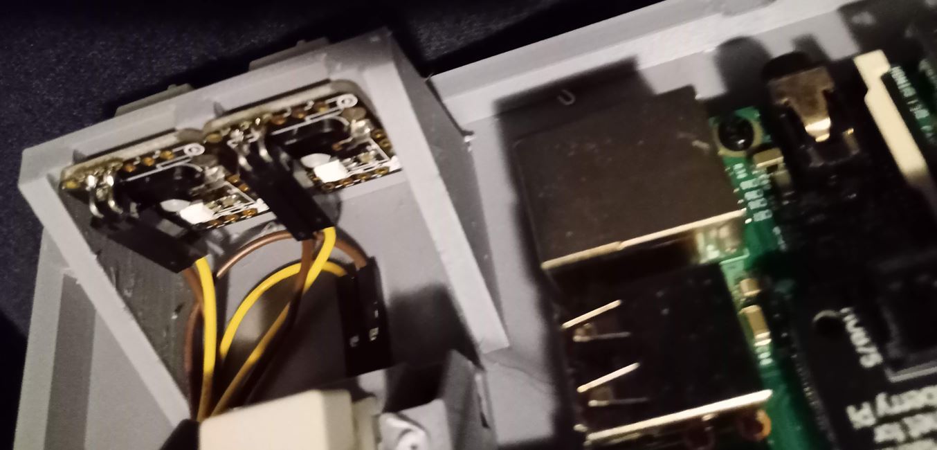
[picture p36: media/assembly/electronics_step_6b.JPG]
electronics - mx switches side


Now we do a similar thing for two *outward-facing* `NeoKeys`. These attach onto a separate small print, which is then attached with two `M2.5` (10mm) screws and hex nuts.

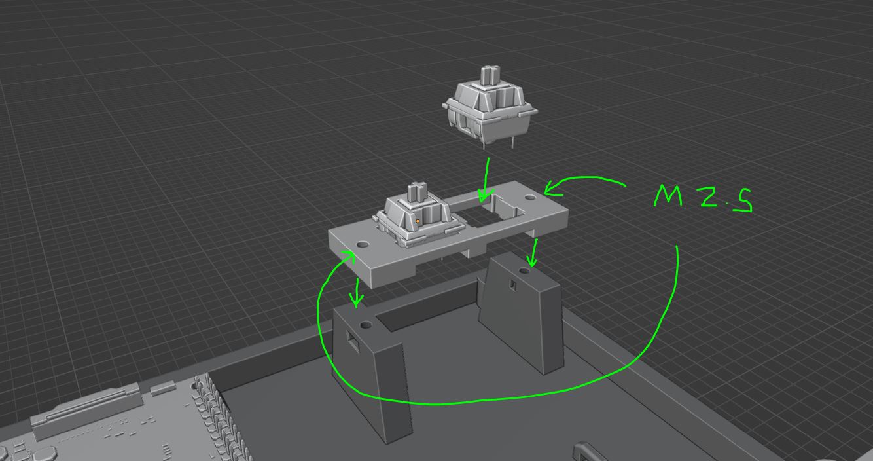
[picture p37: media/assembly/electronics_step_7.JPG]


Attach the `NeoKeys` with the header pins pointing towards the `NeoSlider`. It should looks something like this:

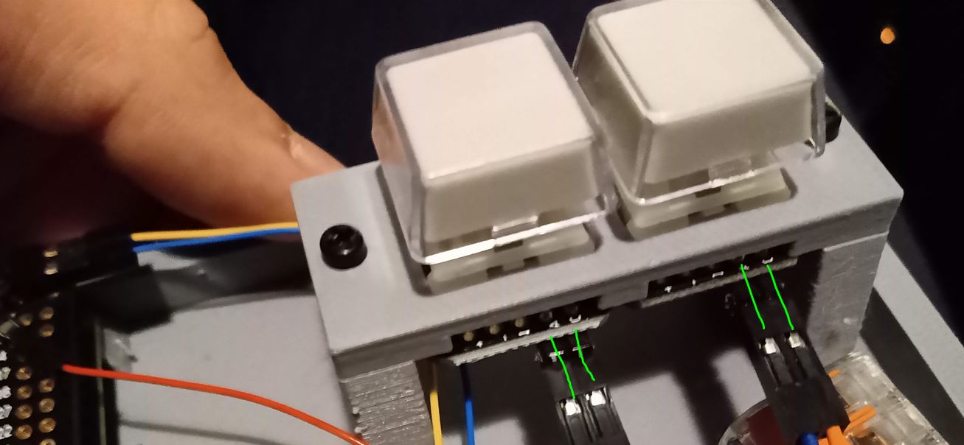
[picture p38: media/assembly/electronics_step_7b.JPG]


Now all we need to do still is set up the main button `NeoKey`. This too attaches to a separate small print. This small print is attached with 4 `M2.5` (6mm) screws and nuts. It might be a bit tricky to get the hex nuts into the slots - but I assure you it is possible 😉.

On the switch, you can mount one of the `Relegendable Plastic Keycaps`, with the clear lid **taken off**. On top of that, the main play button can be placed. 

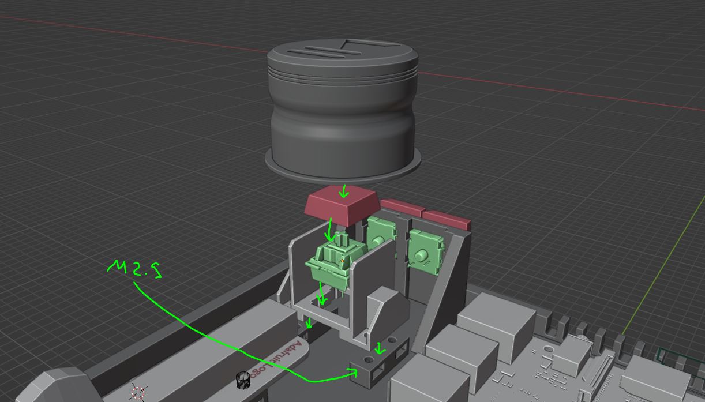
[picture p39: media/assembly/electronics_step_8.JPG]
electronics step - main button


> The `NeoKey` PCB can be mounted either way, with the header pins pointing towards the `NeoSlider` or towards the side button. It doesn't really matter.

**🔌 Wiring **

Everything is in place, let's wire it up! Connect the `Stemma QT` cables to the pins on the `RGB matrix header` in the following way:

* Blue wire to SDA
* Yellow wire to SCL
* Red wire to +3.3V
* Black wire to GND

For all the `NeoKeys`, wire the `S+` keys to the following pins

* Main Button to `MO`
* Back button 1 (closest to Raspberry Pi) to `MI`
* Back button 2 to `CLK`
* Side button 1 (closest to Raspberry Pi) to `CE0`
* Side button 2 to `CE1` 

> **Note**
> If you don't mind soldering many wires together irreversibly, you can solder all the `S-` connections of the `NeoKeys` to the ground pins on the NeoSlider . A slightly nicer approach is to use some kind of [wire block connector](https://www.adafruit.com/product/874).

electronics step - wiring diagram

That should be most of the box set up. If you like, you can use zip ties to keep the cables in check; there are anchor points included on the box to secure the zip ties.

 If everything went well, your setup should now look something like this:

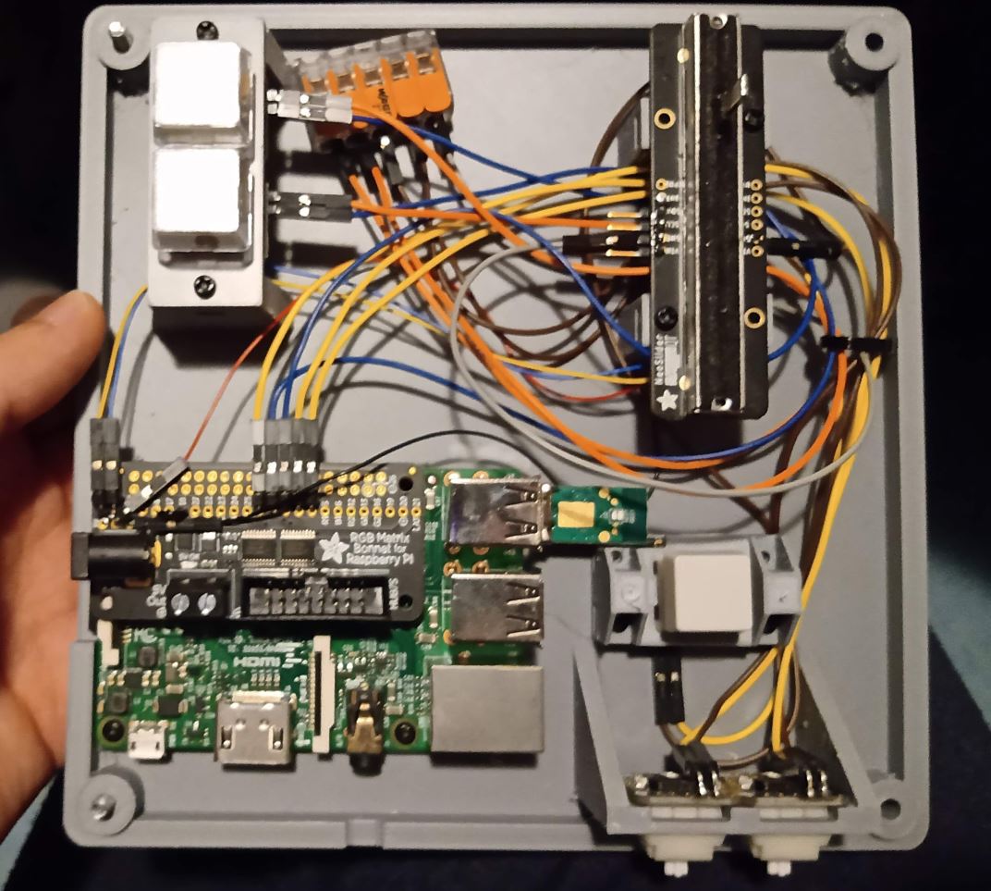
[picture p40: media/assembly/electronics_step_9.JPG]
electronics step - assembly complete
/

> Note that I used a fancy connector (orange) to connect the ground cables together; perf board would work just as well and be a lot cheaper. This connector is just handier during prototyping when it needs to be taken apart a lot.

> Note the weird Bluetooth dongle plugged into the USB port; the one listed in the parts list should be smaller and fit better. If you are using a Pi Zero, no adapter is needed.

#### Connecting the display and final assembly 

Now we are ready to connect the display to the `RGB matrix header`. Connect the ribbon cable (display data) to the corresponding port, and use the screw terminals (display power) to connect the red wire to the positive (+) terminal on the matrix header, and the black wire to the ground terminal (-). Route the cables through the dedicated cutouts on the `top box` indicated below. 

> Note: you will probably need to keep the `top box` with display assembly close to the `bottom box` as the cables are not very long.

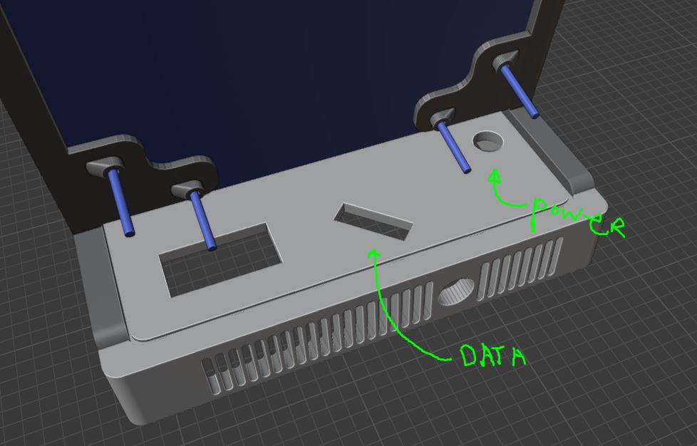
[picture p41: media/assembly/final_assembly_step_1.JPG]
final assembly - wiring cutouts


Connect the data and power cables to the `RGB matrix panel`. 

Now it should be possible to close the assembly by placing the `top box` on top of the `bottom box`. Make sure that the `M4` hex nuts are placed in the 4 corners of the `top box` so the assembly can be firmly locked.

When closing the assembly, it is easiest to tilt in from the left side, and to leave out the keycaps on the side buttons until **after** the assembly is closed. 

> ⚠️ Make sure the main play/pause button is seated when you close the assembly.

> ⚠️ Remove the `NeoSlider` rubber dome before closing the assembly, and put it back on the slider fin when the assembly is closed. It is held in place  by friction, so it can be pulled right off.

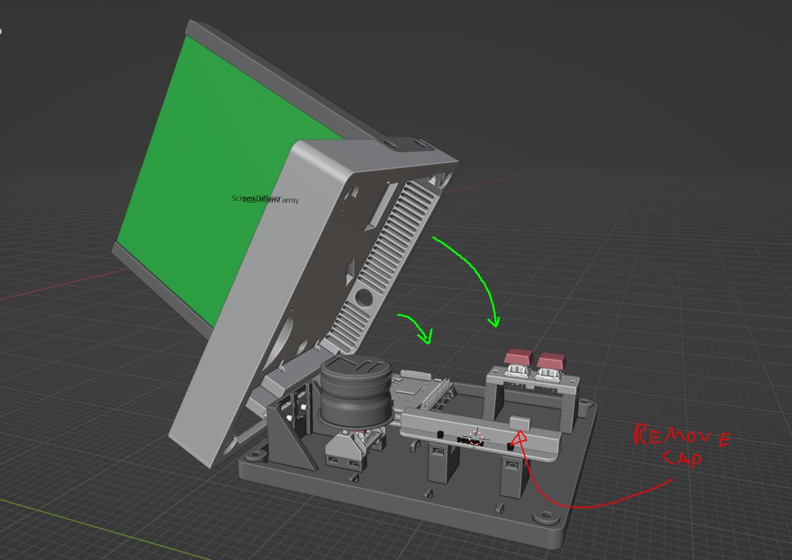
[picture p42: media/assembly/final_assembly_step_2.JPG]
assembly final - closing the enclosure


With the assembly closed, attach the 4 `M4` screws to lock the assembly in place. 

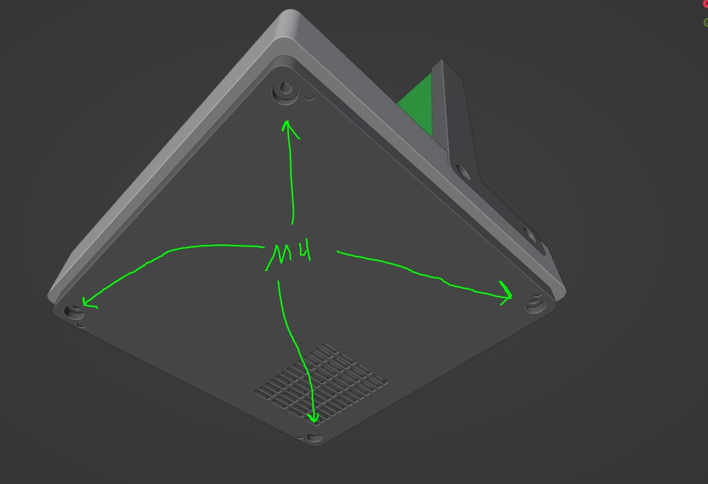
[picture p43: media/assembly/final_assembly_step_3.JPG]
assembly final - adding final bolts


Now you can also add those remaining keycaps to the side buttons. If you had not yet added keycaps to the back buttons, you can do so now as well. Note that the side and back buttons (unlike the one that sits underneath the main play/pause button) should **not** have the clear casing removed.

> Optionally, add some anti-slip pads to the bottom of the player to minimise sliding and to allow some airflow underneath the device.

### You have made it to the end of the assembly process 🥳, now we are ready to [set up the software side](setup.md), and test the hardware!

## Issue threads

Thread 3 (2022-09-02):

Error logging system

NemoAndrea, 2022-09-02:
The player should have some basic logging system that keeps track of errors and crashes.

NemoAndrea, 2022-09-18:
Added basic error logging and capture with the python logging module. Still needs to handle errors better, but now they will be caught and logged so they can be adressed in the future.

Closed 2022-09-18.

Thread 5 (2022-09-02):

Redesign main button mechanism

NemoAndrea, 2022-09-02:
The main play/pause button on the printer is the central user interaction element, but at the moment the experience is usable, but not as smooth or polished as I would like.

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

There are two main reasons for this ⬇️

1. The current main button mechanism uses a standard MX-style switch. This is mechanically ok, but unless you get a very heavy spring, the return force is a bit lacking.

2. In addition, the printed mechanism (two pins) to keep the round button aligned have quite a lot of friction when they are fresh out of the printer. After a while it becomes smooth enough as the printed parts wear out any imperfections in the sidewal.

Help or advice on improving or circumventing the above two issues would be appreciated. Ideally solutions should involve parts that can be sourced relatively easily.

NemoAndrea, 2023-01-14:
Mostly fixed in [this commit](https://github.com/NemoAndrea/SpotiStation/commit/5d482deb6d8d181a65c17f26d2139067322558e3) Revised the design of the button and switch holder, making it have much less friction and binding. In addition the new part is much stronger. The old design often broke after repeated use.

Spring return force might also be less of an issue due to the reduced friction.

Closed 2023-01-14.

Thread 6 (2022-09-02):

Test on Raspberry Pi zero 2W

NemoAndrea, 2022-09-02:
Verify if the [Raspberry Pi Zero 2W](https://www.raspberrypi.com/products/raspberry-pi-zero-2-w/) has enough horsepower to run the **SpotiPlayer** smoothly.

If so, I will make an alternative printable part for the Zero. It would be great if the zero is powerful enough as it could make the project more affordable to build.

NemoAndrea, 2022-09-06:
Thanks to @jerzeek I was able to to run a test with the Raspberry Pi Zero 2(W)! It was able to handle full playback for over an hour and UI seemed responsive enough.  (not a huge surprise given that it's the same CPU just clocked  bit slower apparently)

Surprisingly, it is able to handle playback (wifi) and bluetooth at the same time from the internal wireless module; something that my raspberry pi 3 struggles with. So it seems like a bluetooth dongle is not needed anymore.

NemoAndrea, 2022-09-16:
Documentation is updated to reflect that the Raspberry Pi Zero 2W is now the recommended device. New printable files added to reflect this.

Closed 2022-09-16.

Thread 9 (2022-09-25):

Power consumption measurements

NemoAndrea, 2022-09-25:
## Energy use

The power consumption of the SpotiStation is currently not measured, which makes estimating the running (energy) costs of the device tricky.

In addition, it might be that the current power supply is overkill for the job and a smaller and cheaper supply will do just as well.

## Solution

1. Run measurements with socket power monitor to see how much power display uses (at 50% brightness and 100% brightness)
2. Re-evaluate the suitability of current power supply

NemoAndrea, 2022-12-04:
Measurements were carried out with a simple socket power meter and the results are as follows:

* ~11W with display at 100% and white background (max power draw for display)
* ~5W with display at 50% and white background
* 2-3W with display off (startup and night mode)

> Brightness [set via the display driver](https://github.com/NemoAndrea/SpotiStation/blob/83e93826ac9ac2b98a67a0529c90a9afe7dddfb0/src/display.py#L37), to be moved to the main config file at some point. https://github.com/NemoAndrea/SpotiStation/blob/83e93826ac9ac2b98a67a0529c90a9afe7dddfb0/src/display.py#L37

So this means that a 15W power supply (5V 3A) should be able to run the device just fine. I will remove references to the old 5V 10A supply is it is extremely overkill as expected.

Closed 2022-12-04.

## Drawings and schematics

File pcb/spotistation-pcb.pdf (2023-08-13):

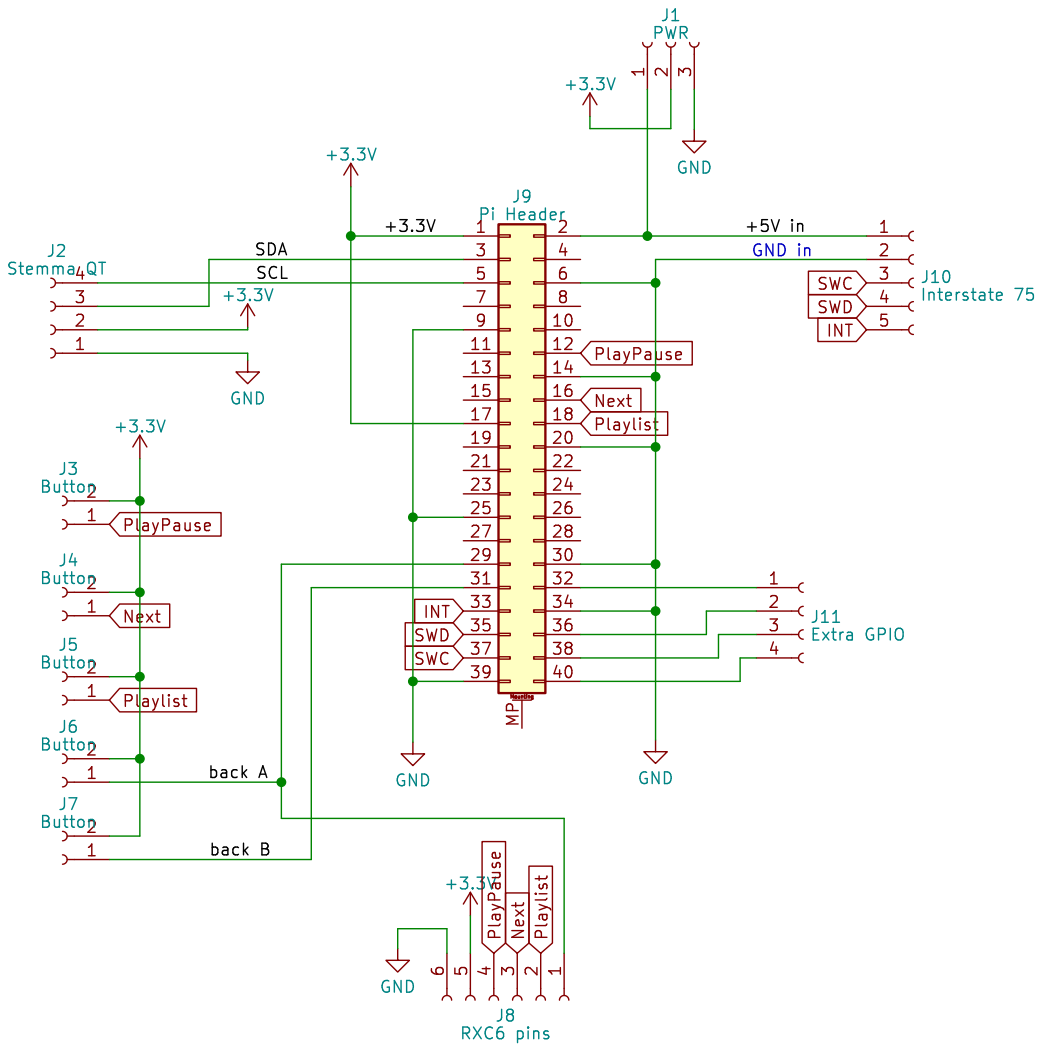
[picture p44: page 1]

31 | 32
33 INT SWC | 34

Id: 1/1 Title: File: spotistation-pcb.kicad_sch Sheet: /

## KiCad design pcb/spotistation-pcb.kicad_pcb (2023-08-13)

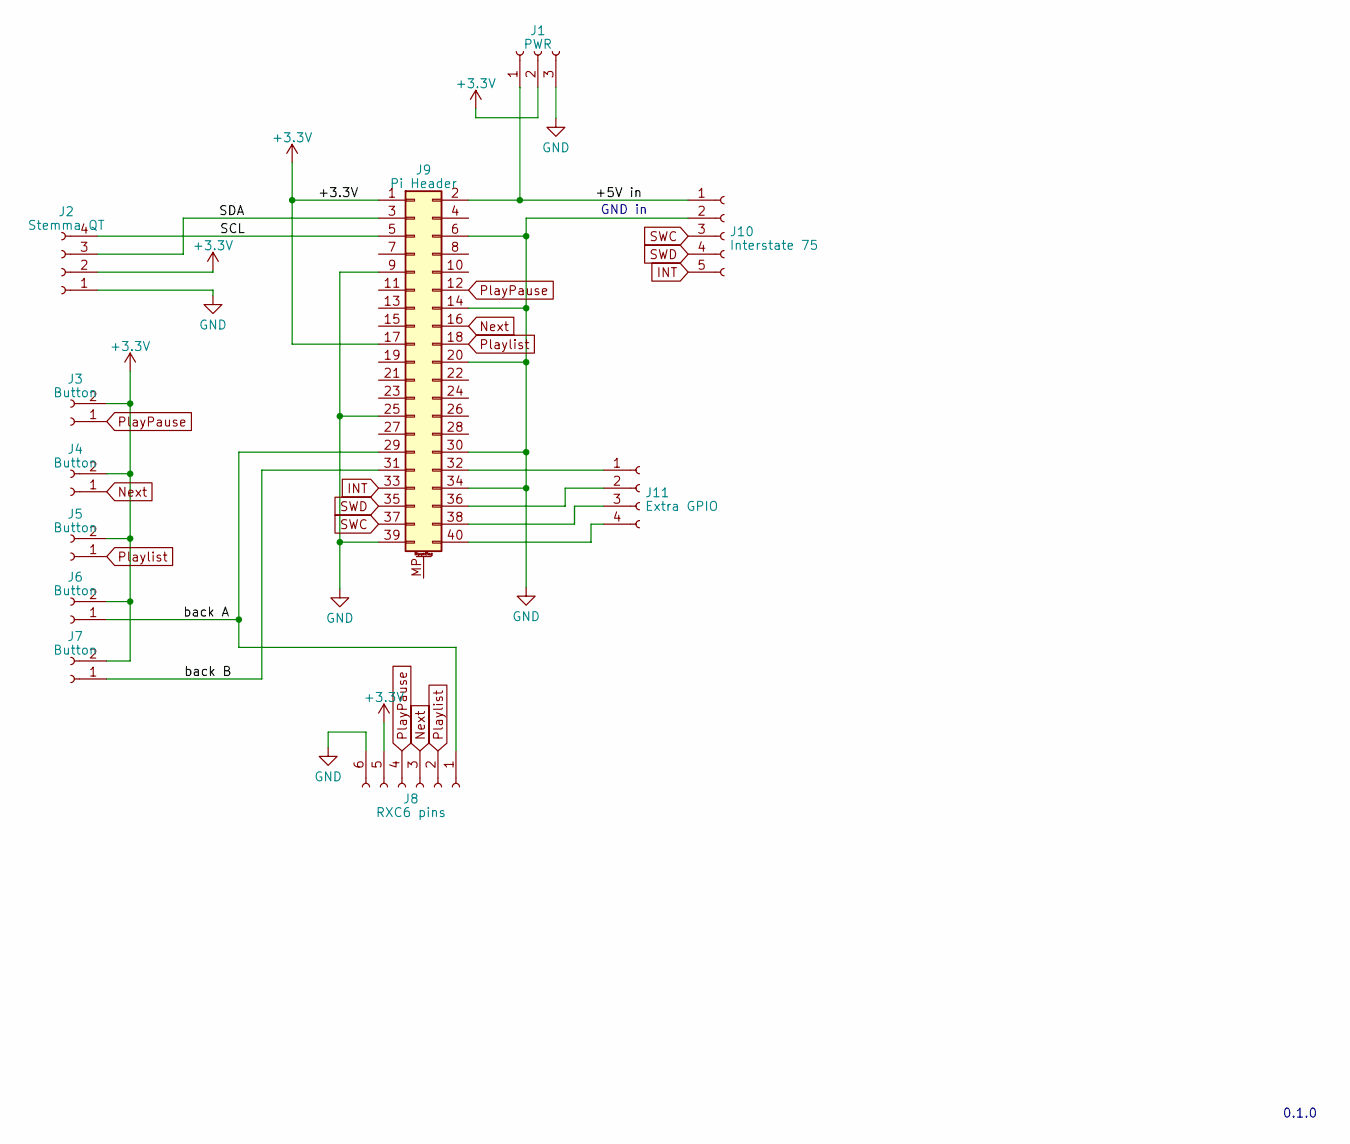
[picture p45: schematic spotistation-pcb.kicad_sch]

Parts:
J1: PWR; PinHeader_1x03_P2.54mm_Horizontal
J2: Stemma QT; PinHeader_1x04_P2.54mm_Horizontal
J3, J4, J5, J6, J7: Button; PinHeader_1x02_P2.54mm_Horizontal
J8: RXC6 pins; PinHeader_1x06_P2.54mm_Horizontal
J9: Pi Header; PinSocket_2x20_P2.54mm_Vertical
J10: Interstate 75; PinHeader_1x05_P2.54mm_Horizontal
J11: Extra GPIO; PinHeader_1x04_P2.54mm_Horizontal

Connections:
+3.3V: J1.2, J2.2, J3.2, J4.2, J5.2, J6.2, J7.2, J8.5, J9.1, J9.17
/+5V in: J1.1, J9.2, J10.1
/SCL: J2.4, J9.5
/SDA: J2.3, J9.3
/back A: J6.1, J8.1, J9.29
/back B: J7.1, J9.31
GND: J1.3, J2.1, J8.6, J9.6, J9.9, J9.14, J9.20, J9.25, J9.30, J9.34, J9.39, J10.2
INT: J9.33, J10.5
unnamed: J9.32, J11.1
unnamed: J9.36, J11.2
unnamed: J9.38, J11.3
unnamed: J9.40, J11.4
Next: J4.1, J8.3, J9.16
PlayPause: J3.1, J8.4, J9.12
Playlist: J5.1, J8.2, J9.18
SWC: J9.37, J10.3
SWD: J9.35, J10.4

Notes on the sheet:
GND in
0.1.0

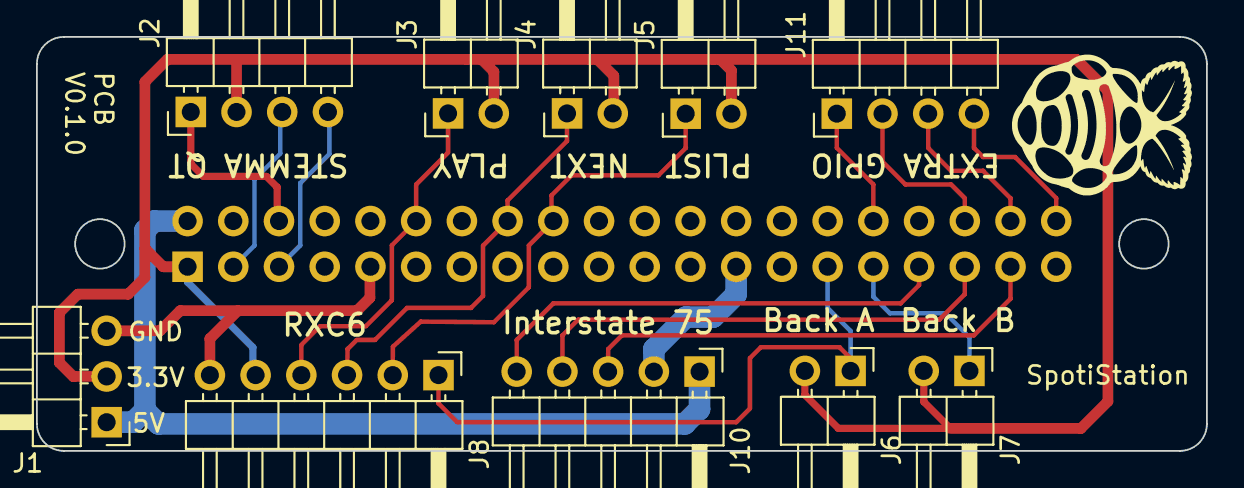
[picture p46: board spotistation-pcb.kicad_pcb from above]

Board: 2 copper layers, 65.0 x 23.0 mm, 11 parts (1 on the bottom side), 17 nets.

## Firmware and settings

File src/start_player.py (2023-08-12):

#!/usr/bin/env python3
import argparse
from copyreg import constructor
import os
import time
import logging
import subprocess

import spotipy
from spotipy.oauth2 import SpotifyOAuth

from read_cache_into_environment import get_spotipy_auth
from setup_hardware import MusicPlayer, PlayerState
from bootmenu import query_boot_mode
from config_manager import update_playlists, get_playlists_in_config, get_device_config, write_device_config
from utils import format_song_info, has_internet_connection, has_bluetooth_connection, setup_logger, get_new_playback, trim_song_name
from quiet_mode import quiet_mode_active, enable_quiet_mode, enable_locked_mode, quiet_mode_enabled_since, set_display_quiet_mode

import alsaaudio  # for mute functionality

'''Raspberry pi music player'''
def start_player(force_local_playback=False, force_playlists=False, log_mode=logging.INFO):
    logger = setup_logger(log_mode)
    logger.info("Starting SpotiStation...")

    ### Hardware setup - create a new MusicPlayer object  

    # this also sets up the display - ROOT is dropped here, be careful about removing/reordering for security.
    player = MusicPlayer()
    
    # wifi and internet checks
    if not has_internet_connection():        
        player.display.set_display_mode("no_wifi")
        time.sleep(30)
        logger.exception("[setup] No internet connection available!", stack_info=True)
        raise Exception("No internet connection available!")
    
    ### Boot Menu

    query_boot_mode(player)  # has to be called after we have established internet connection

    ### Software setup and checks

    config = get_device_config()
    playlist_index = int(config['playback']['current-playlist-index'])
    poll_period = float(config['settings']['playback-poll-period'])

    # # bluetooth checks
    if not config.getboolean('connectivity', 'skip-bluetooth'):  # user can specify to skip connecting
        # check if we are actually able to make a connection to the speaker
        # and try a few times before throwing an error if we cannot find the speaker
        if not has_bluetooth_connection(config['connectivity']['bluetooth-mac']):  
            player.display.set_display_mode("no_bluetooth_audio")
            time.sleep(30)
            logger.exception("[setup] No bluetooth audio connection available!", stack_info=True)
            raise Exception("No bluetooth audio connection available!")

    # check if the spotifyd service is running
    if not os.system('systemctl --user is-active --quiet spotifyd.service')==0:
        player.display.set_display_mode("no_spotifyd")
        time.sleep(30)
        logger.exception("[setup] Spotifyd daemon is not running")
        raise Exception("Spotifyd daemon is not running")

    # quick and dirty get the id, secret and redirect URL into environment variable
    # this assumes the cache_spotipy_credentials.py has been run and .cache was generated before
    # TODO: make this more automatic (no longer manually need to save .creds)
    logger.info("loading client id and secret into environment variables for spotipy")
    get_spotipy_auth()

    # check the Spotipy API 
    try:
        sp = spotipy.Spotify(auth_manager=SpotifyOAuth(cache_path=".cache"))
    except Exception as e:
        logger.exception("Problem setting up Spotipy (python spotify api control).")

    # we need to get a handle on alsa for the mute functionality
    # note that volume adjustment via the slider is handled by a separate python service
    audio = alsaaudio.Mixer()  
    audio.setmute(0)
    if player.state == PlayerState.ACTIVE:
        audio.setmute(0)  # this is insurance in case the player crashes in quiet/lock mode and
                          # comes out in active mode. The system could remain muted without this.

    # this is a bit hacky, but due to some startup sequence issues the volume service will
    # start correctly but not actually control volume. Restarting (sometime after boot) fixes it.
    subprocess.run(["systemctl", "--user", "restart",  "rpi-spotiplayer-volume.service"])

    # wrap everything in try except in order to log issues as they occur
    try:
        # Check that we can find the raspberry pi in playback devices (if spotifyd is working correctly)
        devices = sp.devices()["devices"]
        if not any("SpotiStation" in device["name"] for device in devices):
            # this is a rare case were the spotifyd service is running (which we check above),
            # but not actually working correctly. This can occur e.g. if internet connection is lost
            # and not regained for a while). We manually restart the service and
            # hope it will work after restart. 

            # restart the systemd spotifyd process
            subprocess.run(["systemctl", "--user", "restart",  "spotifyd.service"])

            # throw error (trigger auto-restart)
            errormsg = "Unable to find 'SpotiStation' in spotify playback devices. " \
            "Restarting spotifyd.service in attempt to fix."
            logger.exception(errormsg); raise Exception(errormsg)

        # set the volume for the raspberry pi in _spotify_ to 100%, we will do volume control on
        # device and want to guarantee that it cannot be turned up more than the base setting
        sp.volume(100, next(filter(lambda device: device["name"]=="SpotiStation", devices))["id"])

        # when lanching the player, you may not want to switch to the local device for playback 
        # as you may want to listen on your phone or other set of speakers not controlled by raspberry
        # if NO device is active, we switch to RPi too, as we need something to play on
        player.playback_device = next(filter(lambda device: device["is_active"], devices), None)
        if force_local_playback or player.playback_device == None:
            # we get the current device name. If no spotify app is opened elsewhere, player.playback_device==None
            current_device_name = 'none' if player.playback_device == None else player.playback_device['name']
            if force_local_playback:
                logger.info(f"[flag:force-local-playback] Switching from {current_device_name} to Raspberry " 
                "Pi for playback (--forcelocal is set to True )")
            else:
                logger.info(f"Switching from {current_device_name} to Raspberry Pi for playback")
            # find the raspberry pi in devices
            player.playback_device = next(filter(lambda device: device["name"]=="SpotiStation", devices))        
            # and switch to it
            sp.transfer_playback(player.playback_device["id"])    

        # get the playlists that are in rotation, and check if there are any new playlist in account
        # TODO: handle the limit of 50 playlists (multiple api calls)
        api_playlists = sp.current_user_playlists()
        update_playlists(api_playlists['items'])
        playlists = get_playlists_in_config()['in rotation']

        # Ensure the shuffle mode (on/off) is set correctly from value listed in config
        sp.shuffle(config.getboolean('settings', 'shuffle-songs'))

        # try to find out what we are playing/will be playing
        get_new_playback(sp, player) 

        if force_playlists:  # we are already playing somethign (from e.g. phone) 
            # we check if the current song is in the playlists config, and otherwise switch to one
            # that is in the playlist config 'in rotation' section.
            if player.last_playback['context']['uri'] not in map(lambda x: x[1], playlists):
                logger.info("[flag:force-playlist] switching from ignored/unknown playlist to an in-rotation playlist")
                sp.start_playback(player.playback_device["id"], playlists[playlist_index][1])
        
        # fetch and display the intial playback state
        logger.info(format_song_info(player.last_playback))
        player.display.set_coverart(player.last_playback)  # show the coverart
        if not sp.current_playback()["is_playing"]: player.display.set_display_mode("paused")

        ####################
        ### Main device loop
        ####################

        last_poll_time = time.time()  # initialise
        while True:
            if player.state == PlayerState.ACTIVE:
                if player.playpause.got_pressed():
                    if player.last_playback["is_playing"]:  # get current playback status (play/pause)
                        logger.info("pausing playback")
                        sp.pause_playback()
                        player.display.set_display_mode("paused")
                        # also show the song name at the top of display when track is paused
                        player.display.add_text_to_overlay(trim_song_name(player.last_playback), (32, 5),
                            fill=(255,255,255,200), clear=False)  
                        player.display.add_overlay_to_display(dimming=0.9)
                    else:
                        sp.start_playback()
                        logger.info("starting/resuming playback")
                        player.display.set_display_mode("")

                # side button 1 -> next track
                elif player.sidebutton_1.got_pressed():
                    logger.info("> Skipping track")
                    sp.next_track()  # go to next track
                    # show the next track overlay - it will be cleared when the next track is loaded
                    player.display.set_display_mode("next_track")   

                # side button 2 -> next playlist
                elif player.sidebutton_2.got_pressed():
                    playlist_index = (playlist_index + 1) % len(playlists)
                    playlist_name = playlists[playlist_index][0]
                    logger.info(f">>> Switching playlist to '{playlist_name}'") 
                    # switch to next playlist
                    sp.start_playback(player.playback_device["id"], playlists[playlist_index][1])
                    # show the next playlist overlay - it will be cleared when the next track is loaded
                    player.display.set_display_mode("next_playlist")  
                    playlist_trim = playlist_name[:13] + ".." if len(playlist_name) > 14 else playlist_name
                    player.display.add_text_to_overlay(playlist_trim, (32, 54),
                        fill=(255,255,255,200), clear=False)  
                    player.display.add_overlay_to_display(dimming=0.9)
                    config['playback']['current-playlist-index'] = str(playlist_index)
                    write_device_config(config)  # update the file on disk
                    time.sleep(1)  # ensure the overlay is visible

                # Handle device getting LOCKED by administrator or user
                elif config.getboolean('settings', 'lock-mode-enabled') and player.backbutton_1.got_pressed():                                       
                    logger.info(f"Leaving the ACTIVE state for LOCKED state.") 
                    enable_locked_mode(player, sp, config)
                    continue 

                # check current playback status for changes
                if time.time() - last_poll_time > poll_period:
                    old_playback = player.last_playback
                    get_new_playback(sp, player)  # update playback from API

                    # this is only in case we pause spotify on another device (e.g. phone) - this avoids 
                    # the display pause/play state getting out of sync
                    if player.last_playback["is_playing"] and player.display.overlay_mode=="paused":
                        player.display.set_display_mode("")  # clear the erroneous pause overlay
                    if (not player.last_playback["is_playing"]) and player.display.overlay_mode==None:
                        player.display.set_display_mode("paused")  # add pause overlay that is missing

                    # check if the song has changed (by 'item' id) - in this case the 'current_playback'
                    # could be older than the 'latest_playback'
                    if player.last_playback["item"]["id"] != old_playback["item"]['id']:
                        # update current playback for next loop
                        logger.info(format_song_info(player.last_playback))
                        player.display.set_coverart(player.last_playback) 

                        # set a temporary text overlay showing album name                                             
                        player.display.add_text_to_overlay(trim_song_name(player.last_playback), (32, 5),
                            fill=(255,255,255,200), clear=True)  
                        player.display.add_overlay_to_display_falloff(dimming=0.85, offset=9, length=32) 
                        if config.getboolean('settings', 'fade-song-name'): 
                            player.display.timer.start_timer(3)  # show name for 3 seconds only              

                    last_poll_time = time.time()  # reset poll time

                    # check if we should enter QUIET mode. Don't need to do this often, so we 
                    # put it within this check since it only happens every poll_period
                    if quiet_mode_active(config):
                        logger.info("Leaving the ACTIVE state for QUIET state.")
                        enable_quiet_mode(player, sp, config)  # start quiet mode
                        continue

                # check if overlay should be removed
                if player.display.timer.is_expired():
                    logger.debug("Removing timed display overlay")
                    player.display.reset_overlay() 

                time.sleep(0.05)  # minimum time between ACTIVE loops

            # player in the QUIET state (enabled depending on localtime)
            elif player.state == PlayerState.QUIET:
                if not quiet_mode_active(config):
                    logger.info("Leaving the QUIET state and returning to ACTIVE state")
                    # set the volume back to slider val
                    audio.setmute(0)
                    player.state = PlayerState.ACTIVE
                    player.display.timer.reset()

                # turn off the display if we have been in quiet mode for over 30 minutes.
                if quiet_mode_enabled_since(config, 30):
                    # check for button presses, and temporarily light up display if press detected
                    if player.any_button_got_pressed():                    
                        logger.info("temporarily showing display in QUIET mode")
                        set_display_quiet_mode(player, config)  
                        player.display.timer.start_timer(7)  # show display for 7 seconds                     

                    # if the display timer is active we show the display again, otherwise we turn it off
                    if player.display.timer.is_expired():  
                        player.display.scale_intensity(0) 
                    elif not player.display.timer.is_enabled():  # default action, turn off display
                        player.display.scale_intensity(0)                     

                # set volume to 0 (as someone could still turn ON playback via the API, e.g. via phone)  
                audio.setmute(1)        
                time.sleep(0.3)  # in QUIET mode we don't need to loop fast          
            
            # player is in the LOCKED state (manually enabled by user)
            elif player.state == PlayerState.LOCKED:
                # check for quiet mode set time (overrides locked mode)
                if quiet_mode_active(config):
                    logger.info("Leaving the LOCKED state for QUIET state.")
                    enable_quiet_mode(player, sp, config)  # start quiet mode

                audio.setmute(1)
                time.sleep(0.3)  # in LOCKED mode we don't need to loop fast          
    except KeyboardInterrupt as e:
        logger.warning("SpotiStation interrupted via KeyboardInterrupt")
    except:
        logger.exception("Unhandled exception in SpotiStation playback", stack_info=True)


if __name__ == '__main__':
    parser = argparse.ArgumentParser(description = 'Start the Raspberry Pi music player')
    parser.add_argument('--forcelocal', '-fl', help='Switch current spotify playback device to '
        'raspberry pi when launching.', action="store_true")
    parser.add_argument('--forceplaylists', '-fp', help='Switch playlist if current playlist is ' 
        'is not part of the "in rotation" section in the playlist config file.', action="store_true")
    parser.add_argument('--debug', help='Switch playlist if current playlist is ' 
        'is not part of the "in rotation" section in the playlist config file.', action="store_true")
    args = parser.parse_args()
    
    logmode = logging.DEBUG if args.debug else logging.INFO
    start_player(args.forcelocal, args.forceplaylists, logmode)

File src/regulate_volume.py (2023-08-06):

import time

import alsaaudio

import board 
from adafruit_seesaw.seesaw import Seesaw
from adafruit_seesaw.analoginput import AnalogInput
from adafruit_seesaw import neopixel


class VolumeSlider:
    def __init__(self, potentiometer, neopixel):
        self.slider = potentiometer
        self.led = neopixel

    '''
    Return value of neoslider between 0-1 or None.
    
    Careful: calling `slider.value` in too quick succession seems to result
    in serious errors that require a RPi restart.

    On the RPi the slider returns values outside the spec range [0, 1023]
    this is probably something wrong in the hardware or rpi i2c but we will 
    just have to deal with it by returning None and then handling it. 

    setting RPi i2c bus frequency to 400kHz seems to be a solution, but better be 
    safe than sorry and make sure we can handle an edge case
    '''
    def position(self):
        value = self.slider.value

        if value > 1023:  
            return None
        else:
            return value / 1023  # we will return float between [0, 1]
        

## set up the hardware

neoslider = Seesaw(board.I2C(), 0x30)
potentiometer = AnalogInput(neoslider, 18)
ledpixel = neopixel.NeoPixel(neoslider, 14, 4)

slider = VolumeSlider(potentiometer, ledpixel)

print("i2c slider setup succesful")

## get ready to talk to system volume settings

audio = alsaaudio.Mixer()  # default settings should work
volume = audio.getvolume()[0]  # intialise volume [0-100]

print("alsa-audio connection ok")

print(f"Playback mute state: {audio.getmute()}")
print(f"Mixer ID : {audio.mixerid()}")


## main loop checking for updates in slider state

while True:
    time.sleep(0.1)  # don't need to check more than 10 times per second
    slider_volume = int(slider.position()*100)
    if volume != slider_volume:
        print(f'setting volume to {slider_volume} (0-100)')
        audio.setvolume(slider_volume)
        print(f'system volume is at: {audio.getvolume()[0]}')
        volume = slider_volume

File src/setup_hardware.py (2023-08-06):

import board 
from digitalio import DigitalInOut, Pull
from enum import Enum, auto


from display import MusicDisplay

class MusicPlayer:
    def __init__(self):
        buttons = initialise_buttons()
        self.playpause = buttons[0]
        self.sidebutton_1 = buttons[1]
        self.sidebutton_2 = buttons[2]
        self.backbutton_1 = buttons[3]
        self.backbutton_2 = buttons[4]

        # Set up display - ROOT is dropped here, be careful about removing/reordering for security.
        self.display = MusicDisplay(64, 64)  # needs root privileges, but those are dropped after this function 
        # set the boot screen image 
        self.display.set_image_from_file("./media/interface/splash_screen.png")  

        # current playback device (normally the spotistation itself, but could be another device
        # connected to spotify API)
        self.playback_device = None  
        self.last_playback= None  # we keep track of this in case the API times out
        self.state = PlayerState.ACTIVE

    def any_button_got_pressed(self):
        '''checks if any of the buttons have been pressed.
        
        Functionality is the same as got_pressed for PlayerButton, and hence must be called in a loop
        for it to work properly.'''
        return any([
             self.playpause.got_pressed(),
             self.sidebutton_1.got_pressed(),
             self.sidebutton_2.got_pressed(),
             self.backbutton_2.got_pressed(),
             self.backbutton_1.got_pressed()
        ])
        

class PlayerState(Enum):
    ACTIVE = auto()
    QUIET = auto()
    LOCKED = auto()



def initialise_buttons():
    # play pause button - wired to SPI0_MOSI
    playpause_button = DigitalInOut(board.MOSI)
    playpause_button.pull = Pull.UP

    # back button 1 and 2
    back_button_1 = DigitalInOut(board.MISO)
    back_button_1.pull = Pull.UP
    back_button_2 = DigitalInOut(board.SCLK)
    back_button_2.pull = Pull.UP

    # side button 1 and 2
    side_button_1 = DigitalInOut(board.CE0)
    side_button_1.pull = Pull.UP
    side_button_2 = DigitalInOut(board.CE1)
    side_button_2.pull = Pull.UP

    return [
        PlayerButton(playpause_button),
        PlayerButton(side_button_1), 
        PlayerButton(side_button_2),
        PlayerButton(back_button_1),
        PlayerButton(back_button_2),
    ]

class PlayerButton:
    def __init__(self, button):
        self.button = button
        self.last_value = button.value
    
    '''
    Determine if button just got pressed

    This is a convenience function that only returns true when the button is pressed
    but was not yet pressed (held down) before. If the button is not pressed it will always
    return false. To access the raw button value just use obj.button.value instead of obj.got_pressed()
    '''
    def got_pressed(self):
        # button is physically pressed AND it was not pressed before
        if self.button.value == False and self.last_value != False:  
            self.last_value = self.button.value
            return True
        else:
            self.last_value = self.button.value
            return False

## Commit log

2022-07-09 Intial spotify and bluetooth setup & i2c fix
    Initial instructions on runnable spotify and bluetooth. Also figured out source of issues with neoslider and i2c and found a fix.
    [test_hardware.py, utils.py]
2022-07-17 Working display and playpause/skip track
    Display now fetches cover art correctly upon playback and playpause and skip track buttons work. Added remaining hardware checks.
    [cache_spotipy_credentials.py, display.py, setup_hardware.py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]
2022-07-17 Basic overlay implementation
    Added play/pause and next track overlay and a splash screen
2022-07-18 Add intial 3D printable files
    Basic STL files, needing only minor revisions and possible cleanup of source .blend file
    [Case-DisplayBracket.stl, Case-bottom.stl, Case-top.stl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]
2022-07-24 Setup playlist section
    Add the framework for playlist selection. Still needs a GUI menu to easily select playlists rather than ssh and messing around in a text file.
2022-08-01 Smaller font kerning
    Draw the silkscreen font with 1px kerning to allow more text to be shown on screen at a given moment
2022-08-01 Reorganising of classes
    Move from separate button objects to a convenience class MusicPlayer which makes function call syntax cleaner
2022-08-02 Fix multi-line display issue
    Fix bad performance and display blinking by repeated overlay draws. Now requires explicit overlay-to-image call to add the overlay to the image, to be called when you are done drawing an overlay frame.
    [bootmenu.py, display.py]
2022-08-02 Implemented playlist switching
    Added ability to switch between playlists. Added new flag that forces a local playlist to be chosen. Some documentation improvements.
2022-08-02 Fix: force local playlist flag wasn't implemented correctly
    Now it will do nothing if the current song is part of the in-rotation section, rather than defaulting to picking a random song from the set.
    [start_player.py]
2022-08-02 Added wifi and bluetooth checks
    Simple checks when booting to see if wifi (internet) connection is available and if the device is paired to a bluetooth speaker.
2022-08-02 Fix ip adress display and reorganise files
    Fixed issue with ip adress still using old add_text_overlay instead of the new add_text_to_overlay function syntax. Reorganised interface files under ./media.
    [bootmenu.py, display.py, setup_hardware.py]
2022-08-02 Fix typo in config
    [start_player.py]
2022-08-02 Improved errors and reliability and setup as service
    Added instructions and tests for running a service on startip.
    [config_manager.py, display.py, start_player.py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]
2022-08-27 Implement energy saving night mode
    In QUIET mode display will turn off 30 minutes after the onset of QUIET mode. Pressing any button will temporarily wake the screen to show the QUIET mode panel.
2022-08-27 Show playlist name when switching between playlists
    Simple text overlay now also shows the playlist name.
2022-08-29 Part 1 of assembly documentation
    Added list of materials and costs and some instructions on 3D printed. Also added some missing STL (still need to go over their orienation and scale)
    [BackSwitches-top.stl, MainButton.stl, MainButton_switch_mount.stl]
2022-08-31 Full assembly documentation
    Finished the assembly documentation.
    [SpotiStation_design.blend, parts_V10.blend]
2022-09-13 Add Raspberry Pi Zero 2 option
    Added Raspberry Pi zero 2 as an option to save on assembly costs. Added alternative stl for RPI zero 2. Updated bill of materials to reflect lowered cost.
    [Case-bottom-for-ZERO.stl, SpotiStation_design.blend]
2022-09-14 Fix quiet and lock mode config not being respected
    The master boolean for quiet and lock mode was being ignored. Now read it using configparser getboolean() function to parse yes/no (etc)
    [quiet_mode.py, start_player.py]
2022-09-14 Fix QUIET mode display issue
    Fixed issue where the temporary display wake in QUIET mode was not working. This was related to the timer being reset when a new image is drawn. Also fixed issue where the display energy saving mode (part of QUIET mode) would not enable after midnight. Bit of a hacky solution but good enough I think.
    [quiet_mode.py, start_player.py]
2022-09-18 Add logging
    Add initial version of logging. Current error logging and handling is still a bit rough around the edges, but with the current logging system errors can be caught and then handled properly in future updates.
    [bootmenu.py, config_manager.py, display.py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]
2022-09-18 Show song name on pause screen
    Show the name of the currently playing song on the pause overlay.
2022-09-18 Add option to keep song name on screen
    Add option to prevent the song name from automatically fading on screen.
    [start_player.py]
2022-09-18 Update printable files and docs for display diffuser
    Tested and updated changes to the display brackets. Now made to fit 161x168mm cut acrylic panel. Documentation updated to reflect changes.
    [Case-DisplayBracket.stl, SpotiStation_design.blend]
2022-10-02 Implement quick and dirty fix for playback timeout
    Implement a solution for playback timeout that will work for now, but needs a more proper solution in the future.
    [start_player.py, utils.py]
2022-10-16 Implement fix for rare spotifyd error
    Implement a fix for rare case where spotifyd.service is running, but not working correctly. Not sure if fix will always solve issue, but it should improve device reliability.
    [start_player.py]
2022-11-06 Fix: dangling references to old system
    Some incorrect varaibles were still referenced. Now seems to run without issues again.
    [start_player.py]
2022-12-04 Change to parts list: power supply
    Based on recent tests discussed in https://github.com/NemoAndrea/SpotiStation/issues/9 I have switched out the suggested power supply for a lower power variant which reduces cost and probably increases efficiency. Certainly makes for a more compact solution.
2022-12-11 Update setup.md
    fix error in raspi i2C config
2022-12-11 Fix error logging call
    Error in key function that handles API calls and timeout.
    [utils.py]
2022-12-12 Fix issue with api timeout when paused for long periods of time
    Implented a fix for API call timeouts when the player has been left paused for a long time and 'currently playing' becomes None according to the API.
    [start_player.py, utils.py]
2022-12-19 Update setup.md with repo cloning information
    Added information about how to clone the repository onto the raspberry pi. Fixed some outdated image and added preview image for spotify interface.
2022-12-20 Update hardware assembly instructions
    Instructions were missing critical soldering step for display bonnet (solder backside pad E -> 8) which would cause stange issues with display driving.
2023-01-08 Add shuffle option
    Add option to shuffle all playlists via the main config file. In the future a button to toggle shuffle might be added. (e.g. longpress next track)
2023-01-14 New PlayPause button mechanism
    Revised the design for the main play/pause button to be much more robust and have less binding. Return force is still a problem, but at least the part will no longer break under repeated use. Part of a larger migration to FreeCAD for the source designs.
    [MainButton.stl, MainButton_switch_mount.stl]
2023-01-29 Update assembly documentation
    Correct error in images, expanded grounding instructions and show the correct updated playpause button mount part.
2023-05-12 Move design files over to FreeCAD
    Redid the design in FreeCAD instead of blender. There are extremely minor differences between the versions. Replaced the STLs with the ones matching the freeCAD design.
    [BackSwitches-top.stl, Baseplate-button-bracket.stl, Case-DisplayBracket.stl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]
2023-08-06 Run volume control as separate service
    Move the volume slider and system volume as a separate script and service to ensure it remains active if the main script crashes. Improved system mute functionality to use system-level muting.
    [display.py, quiet_mode.py, regulate_volume.py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]
2023-08-12 Basic bluetooth config in boot menu
    Added a basic configuration option in the boot menu to skip the bluetooth connection. Reordered some of the checks in the boot sequence
    [bootmenu.py, start_player.py]
2023-08-13 Add basic shim PCB
    [edge-cuts.FCStd, edge-cuts.dxf, spotistation-pcb.kicad_pcb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]
2023-08-20 Add wireless remote build
    Add instructions and files for a simple 433 MHz remote to control the basic functionality of SpotiStation
    [433_remote_base.step, 433_remote_button_LEFT.step, 433_remote_button_RIGHT.step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]
